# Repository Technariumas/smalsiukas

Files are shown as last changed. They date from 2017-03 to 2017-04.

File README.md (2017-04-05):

# smalsiukas
The conversion of a forklift trucks to a line following robot. 

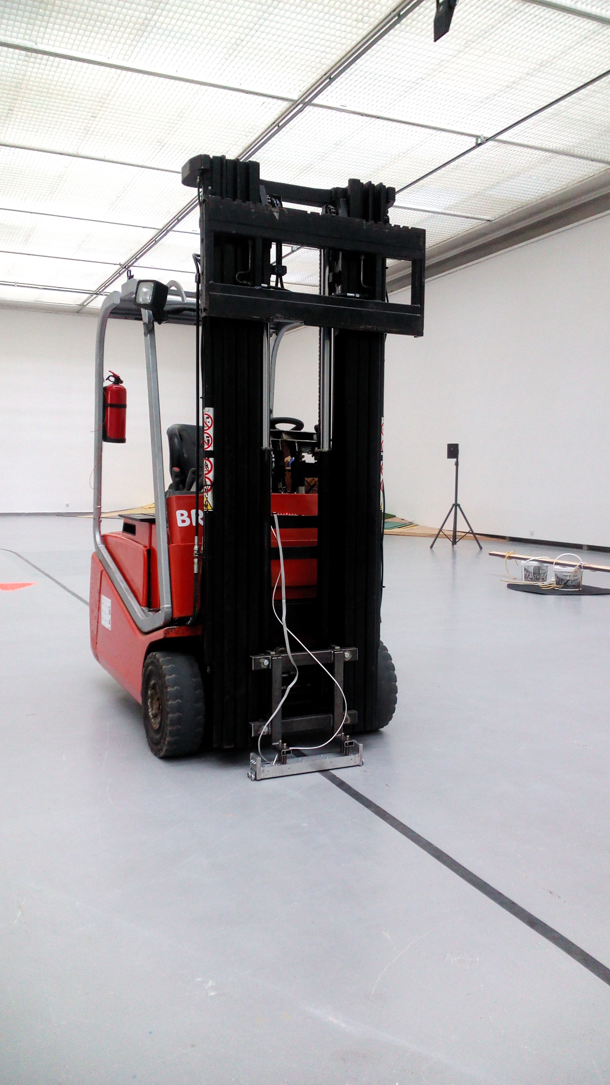
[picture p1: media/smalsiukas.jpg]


A file set related to conversion of BT C3E C4E forklift truck and Linde lifter to a line-following robot for an art installation of [Robertas Narkus "Träger"](http://cac.lt/en/exhibitions/future/8547)

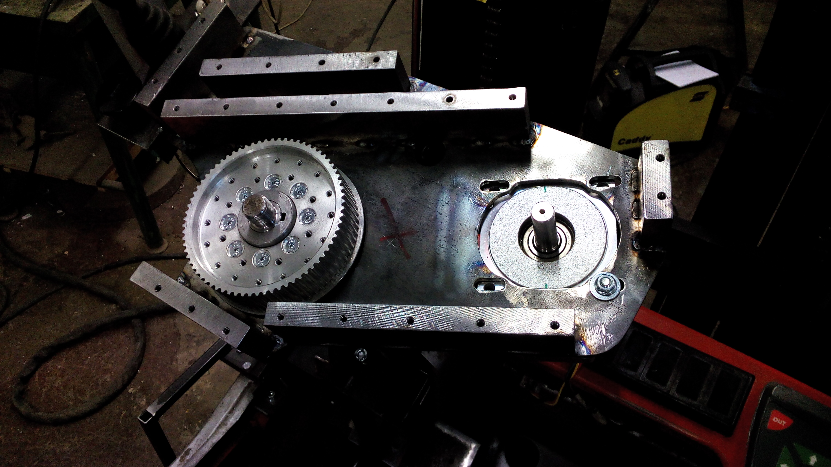
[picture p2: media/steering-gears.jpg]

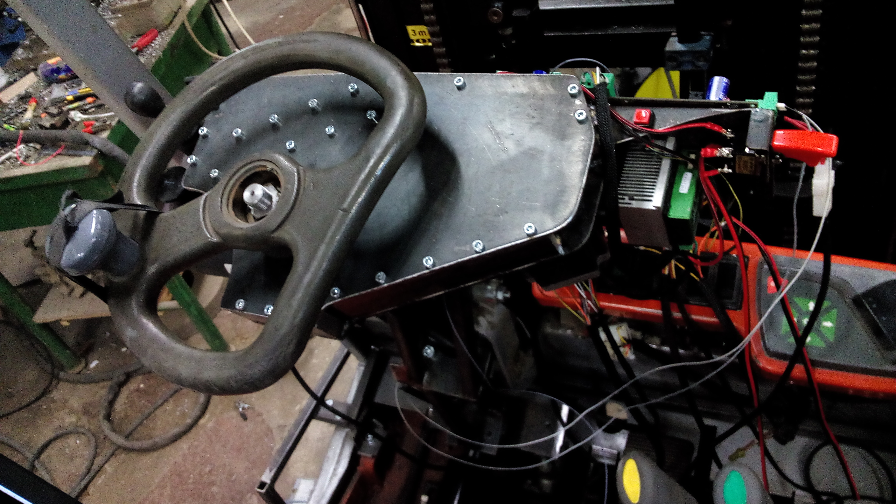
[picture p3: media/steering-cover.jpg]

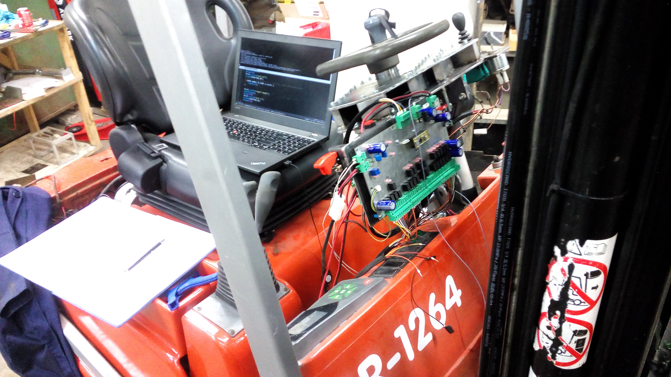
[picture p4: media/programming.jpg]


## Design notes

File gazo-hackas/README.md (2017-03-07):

#Gazo pedalo hackas

schema

##Faktai apie gazo pedalą
 
 * Egzistuoja SPDT jungiklis, kuris laiko užtrumpintus Juodą/Raudoną laidus, kol pedalas nenuspaustas ir Juodą/Mėlyną, kai nuspaustas. Perėjimas iš vienos būsenos į kitą turi būti "greitas", kitaip metama klaida **C4** - pedalo mygtuko klaida.
 * Egzistuoja potenciometras, sukiojamas pedalu jį spaudžiant. Potenciometro bendra varža - 3,6k, wiperio varža nuo potenciometro galų keičiasi 4,6k - 3,7k nuo "aukštojo" galo ir 1,2k - 2,12k nuo "žemojo" galo. Išvada - tai 3,6k potenciometras su 1k rezistoriumi ant išėjimo.
 * Į potenciometrą Žaliu laidu paduodama 10V įtampa, greičiausiai nuosekliai yra pajungtas 500 Omų rezistorius, nes pajungus potenciometrą ant Žalio laido įtampa pasikeičia į 8,7V
 * Keltuvas tikisi, kad potenciometras bus pajungtas ir ant Geltono laido bus ~8,7V, kitaip metama klaida **C6**
 * Kai pedalas nepaspaustas, keltuvas tikisi, kad ant Raudono laido (potenciometro wiperio) bus apie 0,22V, min 0,08V, jei Raudonas laidas paliekamas plaukiot arba pajungiamas prie potenciometro GND, metama klaida **C6**
 * Kai pedalas pilnai paspaustas, ant wiperio būna 2,36V
 * "Iš jausmo", atrodo, kad mums pilnai užtektų greičio ant wiperio esant 0,5V

##Hacko strategija:

  * Užtrumpinti mygtuko Juodą ir Raudoną laidus
  * Mygtuko laidų konfigūraciją perjunginėti rele, kad būtų "greitai"
  * Tarp Žalio ir Geltono laido pastatyti 3,6k rezistorių
  * Ant potenciometro Raudono laido paduoti valdančią įtampą referencintą nuo Geltono laido

##Galvaniškai atsietas Hackas

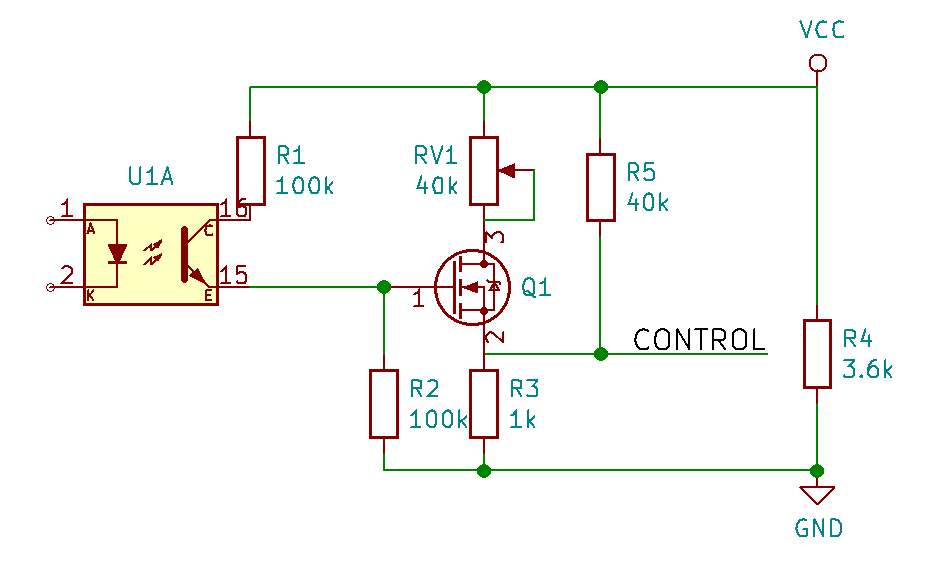
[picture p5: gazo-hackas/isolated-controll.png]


R4 apsimeta, kad pedalo potenciometras yra pajungtas, R5 ir R3 sukuria valdymo įtampą, imituojančią "nepaspaustą" pedalą. Per optoporą įjungus tranzistorių Q1, potenciometras RV1 pajungiamas lygiagrečiai su R5 tokiu būdu pakeliant valdymo įtampą. R2 pririša Q1 užtūrą, kad jis atsitiktinai nesijunginėtų. R1 ir R2 sudaro daliklį, kuris apsaugo Q1 užtūrą nuo viršįtampio.

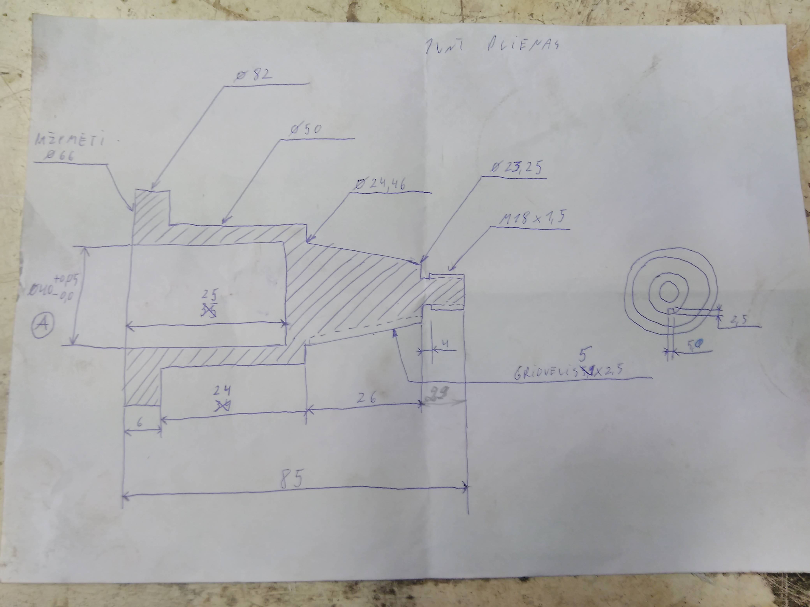
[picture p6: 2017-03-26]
Toyota/Mechanics/Blueprints/Toyota steering wheel hub blueprint.jpg

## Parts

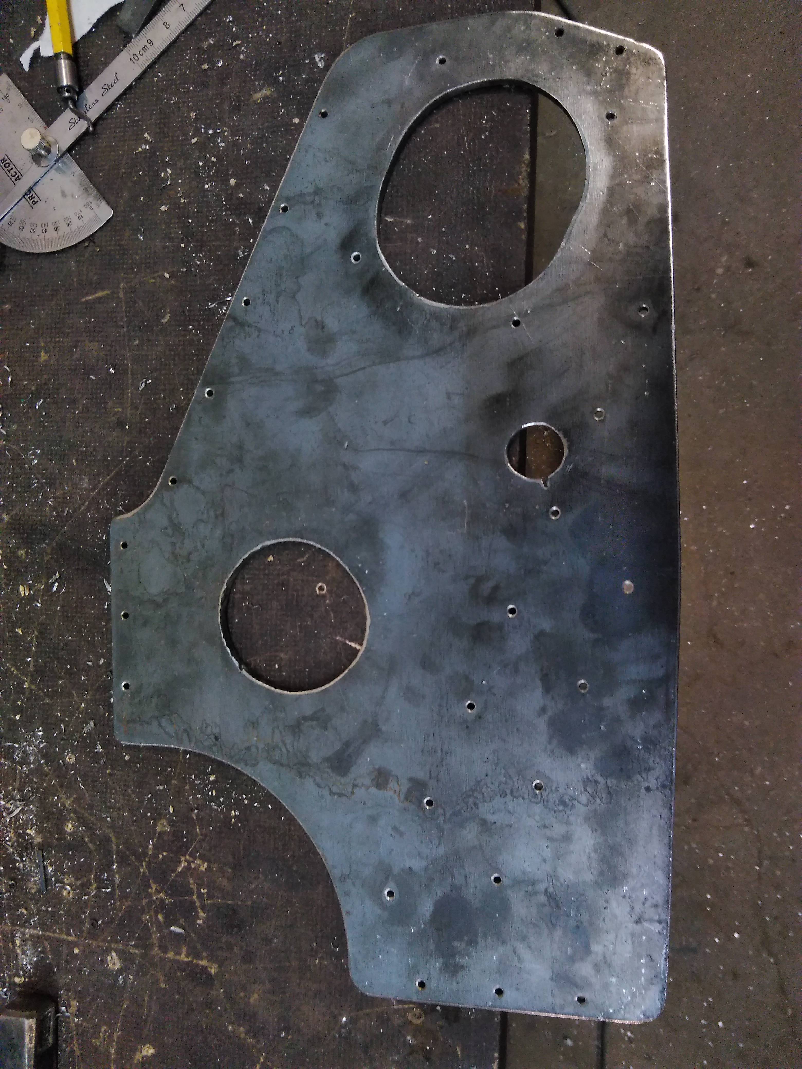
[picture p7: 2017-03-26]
Toyota/Mechanics/Parts/steering wheel/Toyota steering wheel plate.jpg

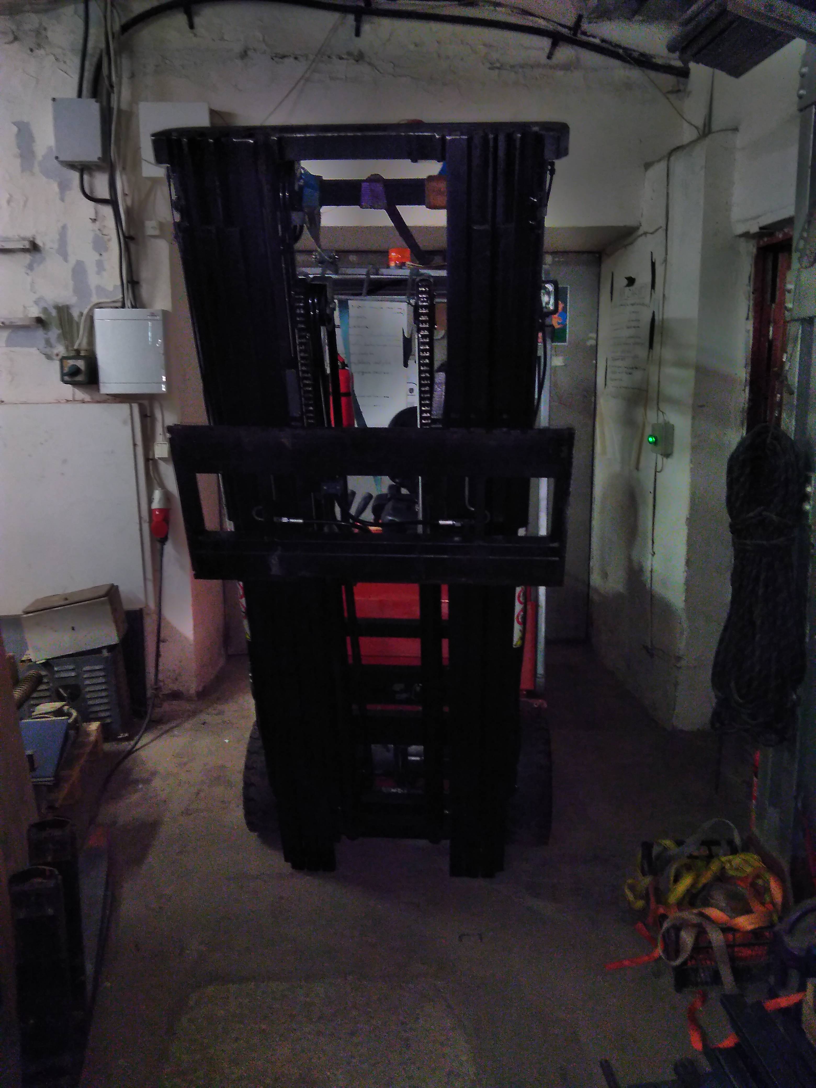
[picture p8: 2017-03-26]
Toyota/Mechanics/Parts/random/Getting in1.jpg

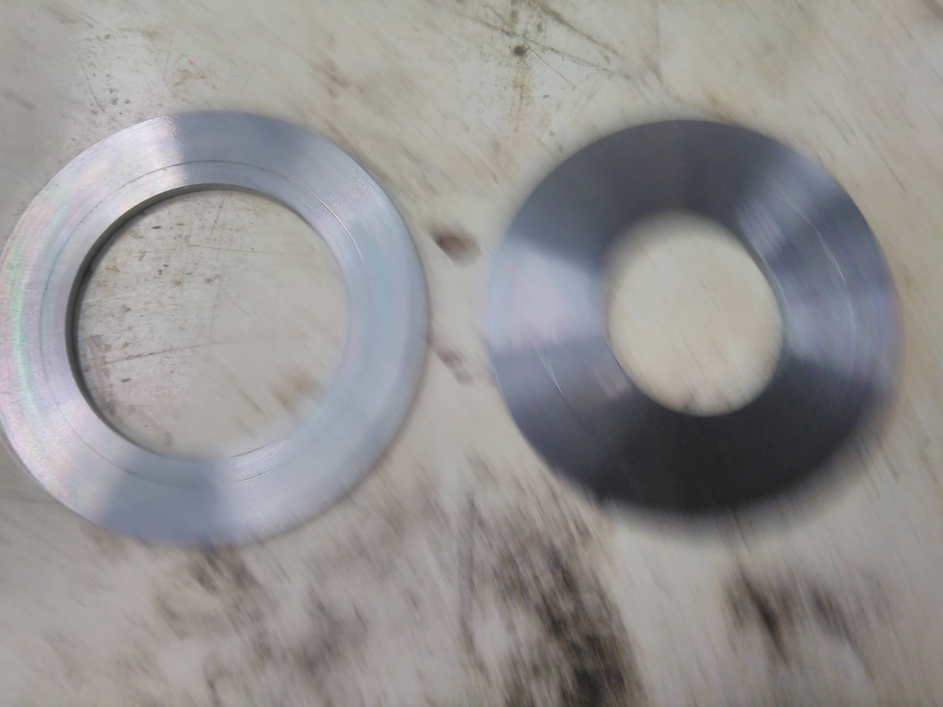
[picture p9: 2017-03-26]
Toyota/Mechanics/Parts/steering wheel/Toyota steering wheel parts.jpg

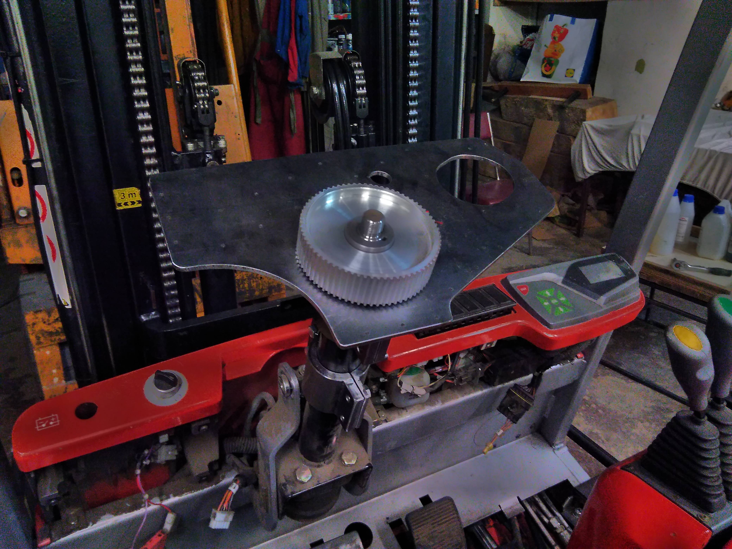
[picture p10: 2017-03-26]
Toyota/Mechanics/Parts/steering wheel/Toyota steering wheel attachment.jpg

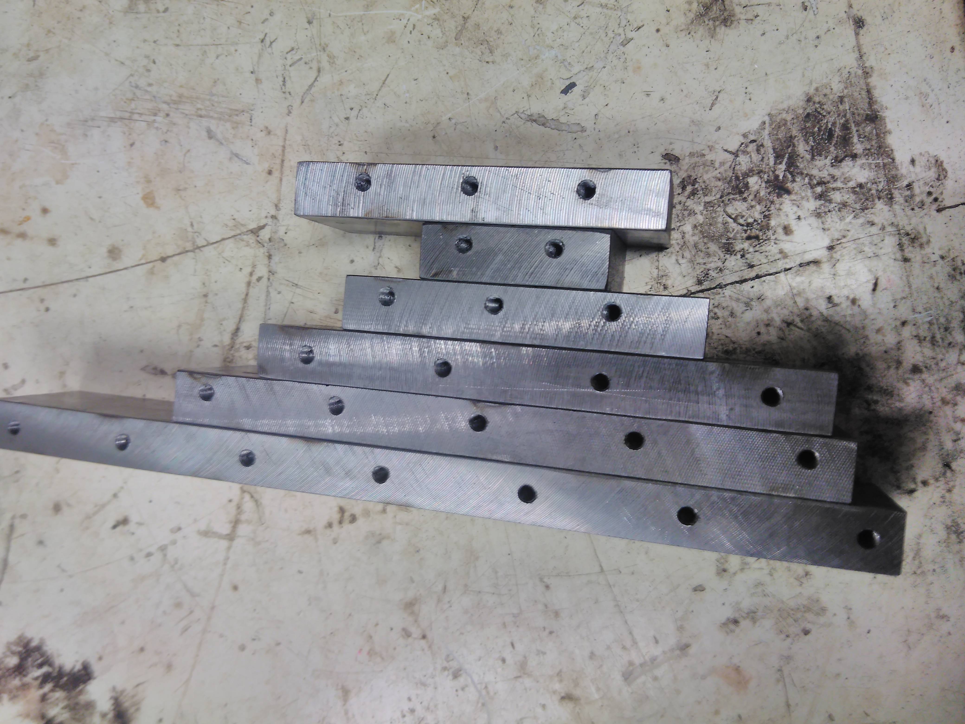
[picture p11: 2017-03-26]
Toyota/Mechanics/Parts/steering wheel/Toyota steering wheel plate standofs.jpg

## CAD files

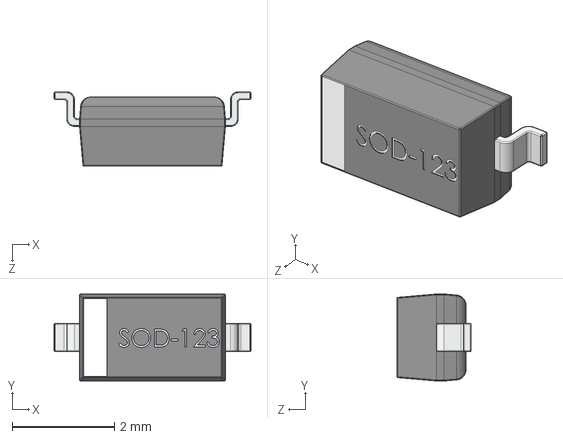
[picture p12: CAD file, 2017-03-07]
line-interface/User Library-SOD-123_DiodesInc.step
3.85 x 1.70 x 1.45 mm

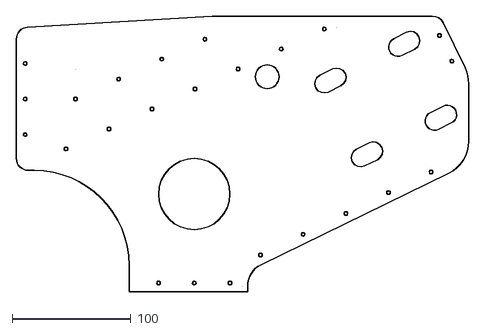
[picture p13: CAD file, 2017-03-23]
Toyota/Mechanics/Blueprints/Toyota drive wheel 1pcs 6mm stepper holes.dxf
381.2 x 232.5

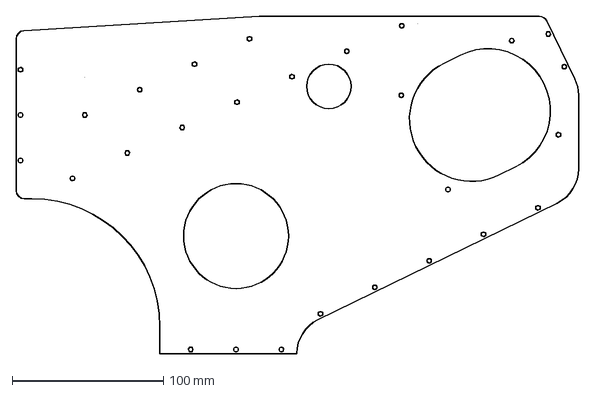
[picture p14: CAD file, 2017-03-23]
Toyota/Mechanics/Blueprints/Toyota drive wheel 2pcs 6mm ply scaled.dxf
371.8 x 223.1 mm

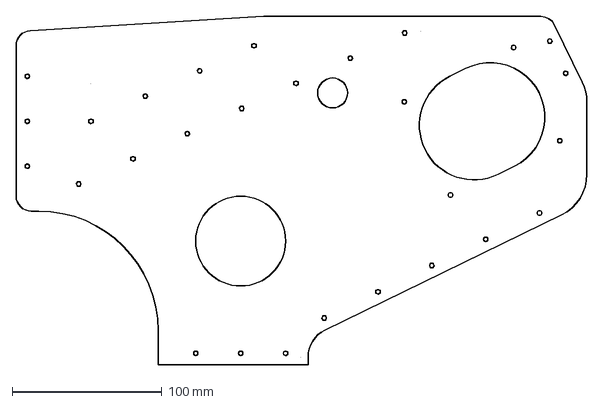
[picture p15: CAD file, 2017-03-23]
Toyota/Mechanics/Blueprints/Toyota drive wheel 1pcs 6mm ply normal.dxf
381.2 x 232.5 mm

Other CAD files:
Toyota/Mechanics/Blueprints/Toyota drive wheel plasma.dwg
Toyota/Mechanics/Blueprints/Toyota drive wheel 2pcs 6mm ply.dwg

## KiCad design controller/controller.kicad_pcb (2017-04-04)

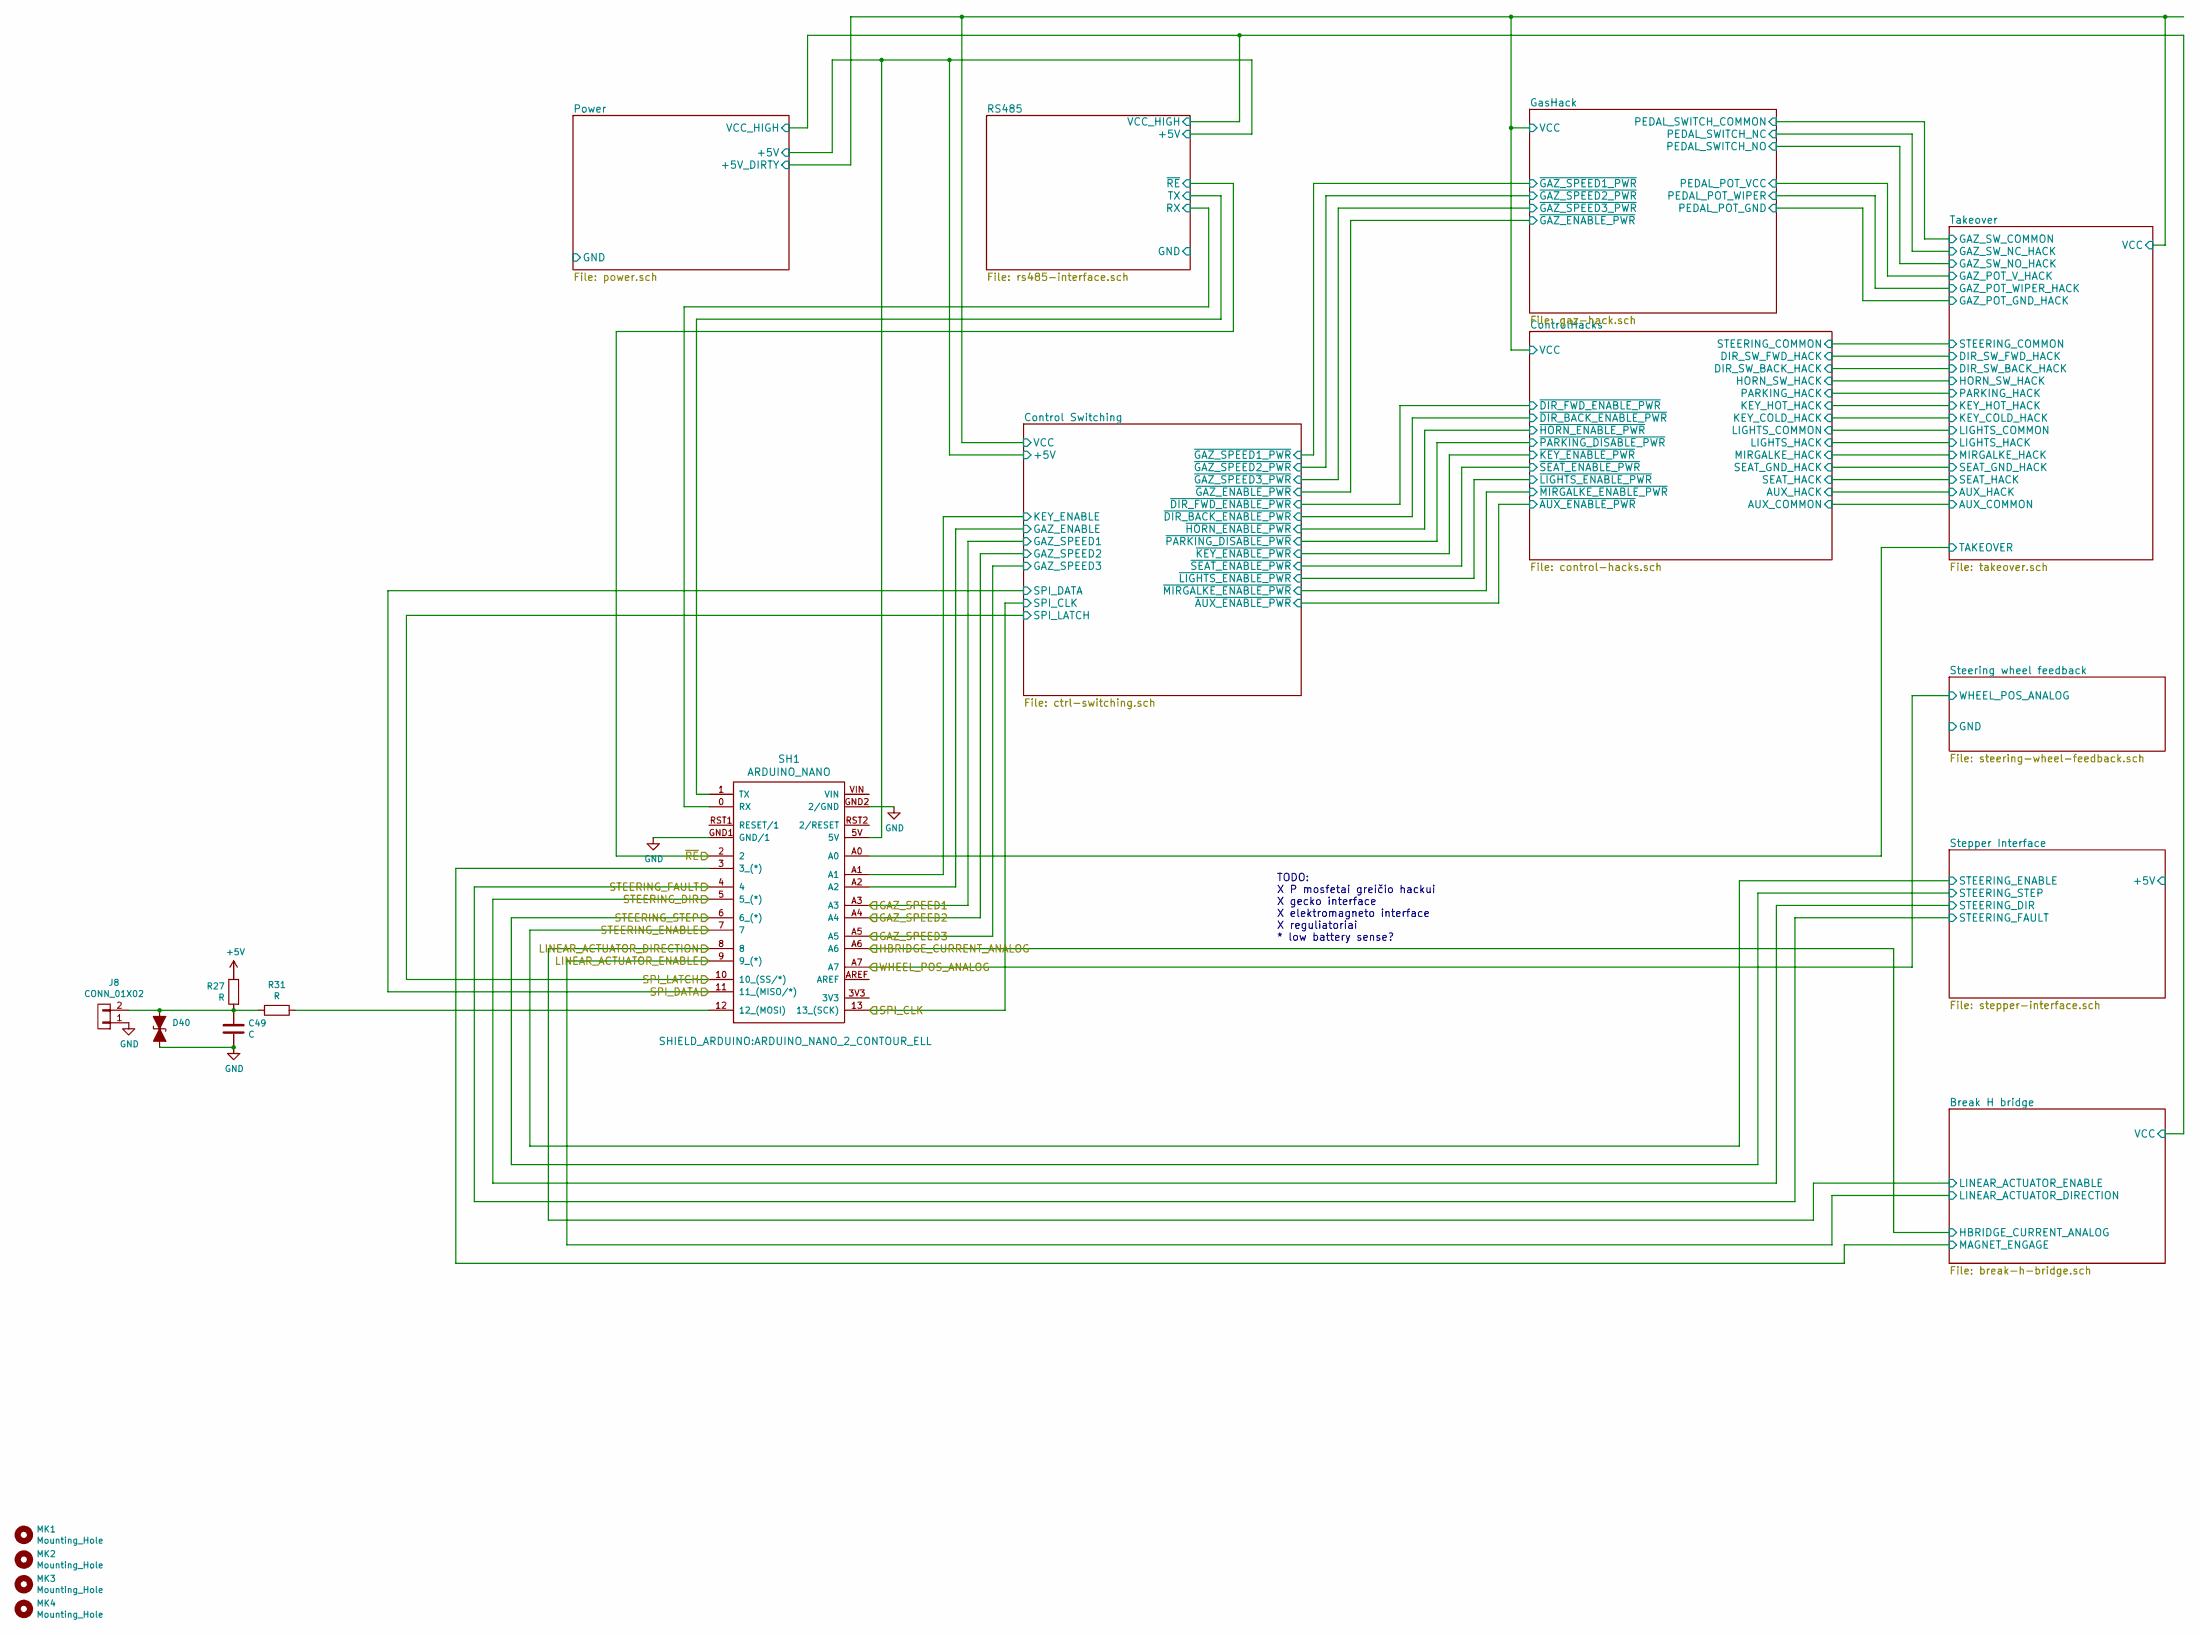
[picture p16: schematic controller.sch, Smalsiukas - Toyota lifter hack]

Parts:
C49: C; C_0603_HandSoldering; PartNo ?
D40: D_TVS_ALT; SOD-323; PartNo ?
J8: CONN_01X02; JST_EH_B02B-EH-A_02x2.50mm_Straight; PartNo ?
MK1, MK2, MK3, MK4: Mounting_Hole; MountingHole_3.2mm_M3; PartNo ?
R27, R31: R; R_0603_HandSoldering; PartNo ?
SH1: ARDUINO_NANO; ARDUINO_NANO_2_CONTOUR_ELL; PartNo ?

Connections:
+5V: R27.1, SH1.5V; also elsewhere on the board
/Break H bridge/MAGNET_ENGAGE: SH1.3 (3_(*)); also elsewhere on the board
/Control Switching/GAZ_ENABLE: SH1.A2; also elsewhere on the board
/Control Switching/KEY_ENABLE: SH1.A1; also elsewhere on the board
/GAZ_SPEED1: SH1.A3; also elsewhere on the board
/GAZ_SPEED2: SH1.A4; also elsewhere on the board
/GAZ_SPEED3: SH1.A5; also elsewhere on the board
/HBRIDGE_CURRENT_ANALOG: SH1.A6; also elsewhere on the board
/LINEAR_ACTUATOR_DIRECTION: SH1.8; also elsewhere on the board
/LINEAR_ACTUATOR_ENABLE: SH1.9 (9_(*)); also elsewhere on the board
/RS485/RX: SH1.0 (RX); also elsewhere on the board
/RS485/TX: SH1.1 (TX); also elsewhere on the board
/SPI_CLK: SH1.13 (13_(SCK)); also elsewhere on the board
/SPI_DATA: SH1.11 (11_(MISO/*)); also elsewhere on the board
/SPI_LATCH: SH1.10 (10_(SS/*)); also elsewhere on the board
/STEERING_DIR: SH1.5 (5_(*)); also elsewhere on the board
/STEERING_ENABLE: SH1.7; also elsewhere on the board
/STEERING_FAULT: SH1.4; also elsewhere on the board
/STEERING_STEP: SH1.6 (6_(*)); also elsewhere on the board
/Takeover/TAKEOVER: SH1.A0; also elsewhere on the board
/WHEEL_POS_ANALOG: SH1.A7; also elsewhere on the board
/~RE: SH1.2; also elsewhere on the board
GND: C49.2, D40.2 (A2), J8.1, SH1.GND1 (GND/1), SH1.GND2 (2/GND); also elsewhere on the board
unnamed: C49.1, D40.1 (A1), J8.2, R27.2, R31.2
unnamed: R31.1, SH1.12 (12_(MOSI))

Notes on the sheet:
TODO: X P mosfetai greičio hackui X gecko interface X elektromagneto interface X reguliatoriai * low battery sense?

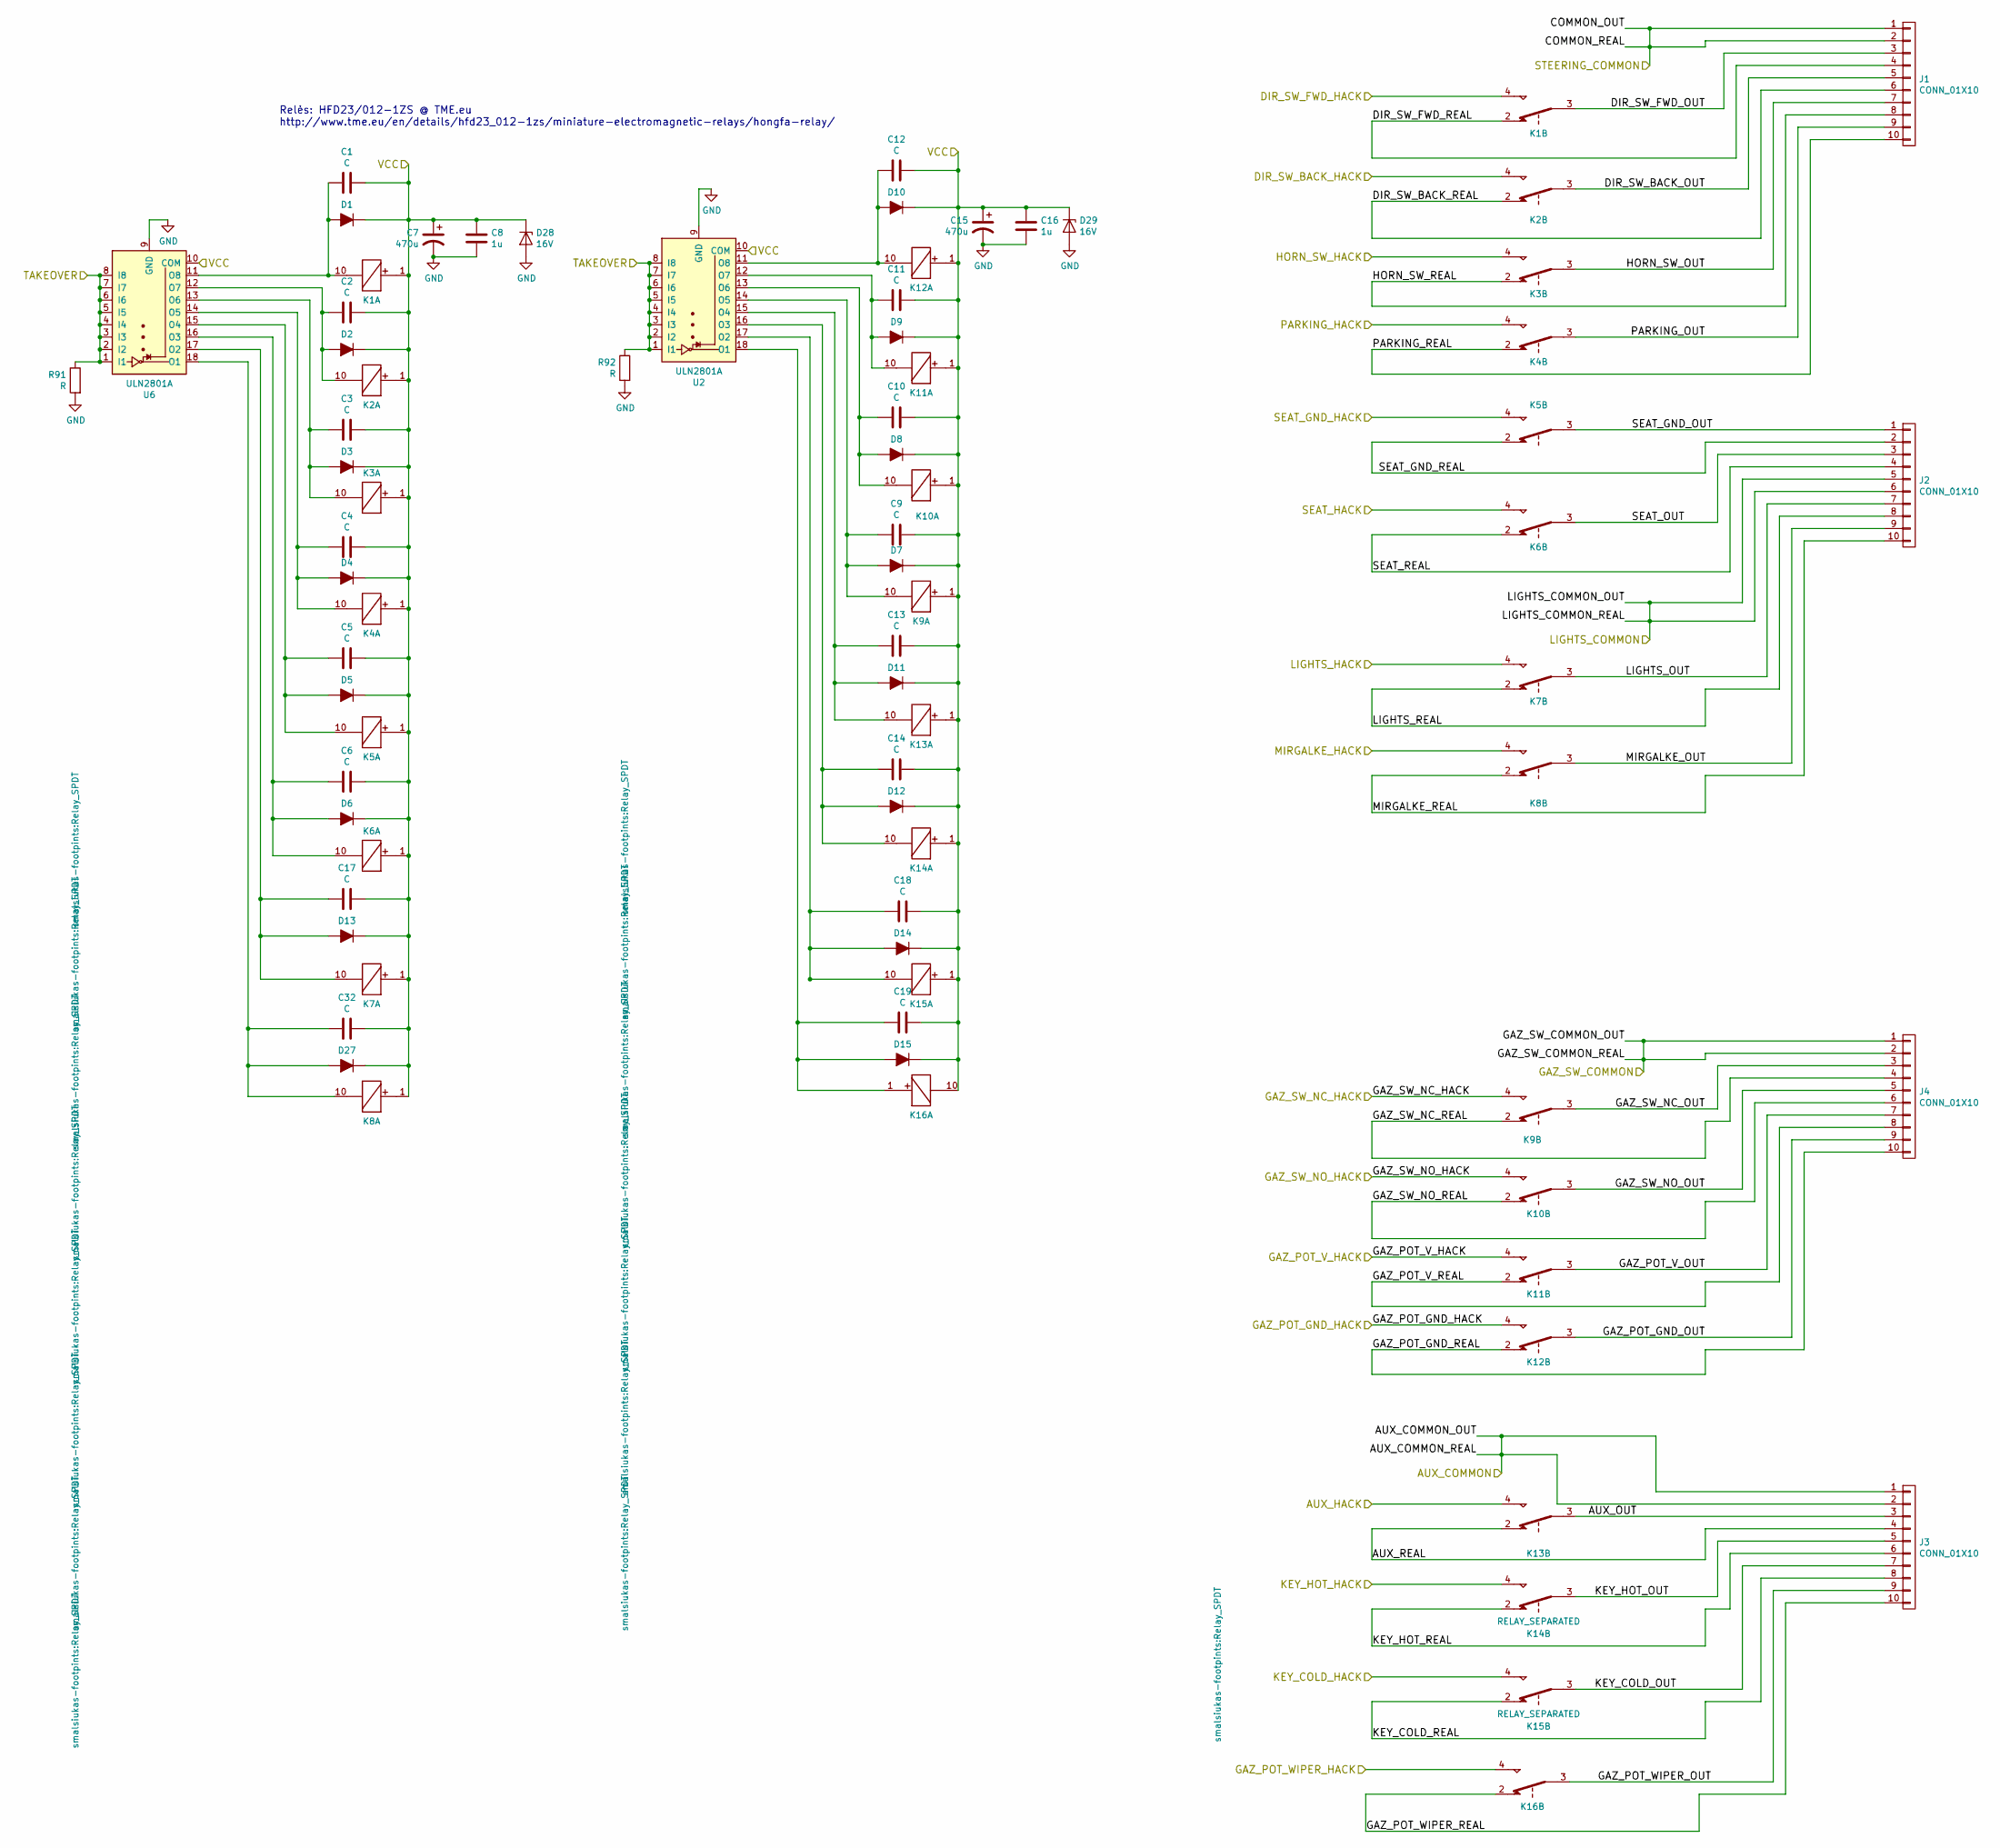
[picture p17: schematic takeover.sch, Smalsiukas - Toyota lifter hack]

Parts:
C1, C2, C3, C4, C5, C6, C9, C10, C11, C12, C13, C14, C17, C18, C19, C32: C; C_0603_HandSoldering; PartNo ?
C7, C15: 470u; CP_Radial_D16.0mm_P7.50mm; PartNo ECA2AAM471X
C8, C16: 1u; C_1210_HandSoldering; PartNo ?
D1: D_ALT; D_SOD-123; PartNo PMEG2020EH
D2, D3, D4, D5, D6, D7, D8, D9, D10, D11, D12, D13, D14, D15, D27: D_ALT; D_SOD-123; PartNo ?
D28, D29: 16V; D_SMB_Handsoldering; PartNo 1SMB5930BT3G
J1, J2, J3, J4: CONN_01X10; TerminalBlock_5.08-10pol; PartNo 21.95MH/10-E
K1, K2, K3, K4, K5, K6, K7, K8, K9, K10, K11, K12, K13, K14, K15, K16: RELAY_SEPARATED; Relay_SPDT; PartNo ?
R91, R92: R; R_0603_HandSoldering
U2, U6: ULN2801A; SOIC-18W_7.5x11.6mm_Pitch1.27mm; PartNo ULN2803ADWR

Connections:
/ControlHacks/AUX_COMMON: J3.1, J3.2; also elsewhere on the board
/ControlHacks/AUX_HACK: K13.4; also elsewhere on the board
/ControlHacks/DIR_SW_BACK_HACK: K2.4; also elsewhere on the board
/ControlHacks/DIR_SW_FWD_HACK: K1.4; also elsewhere on the board
/ControlHacks/HORN_SW_HACK: K3.4; also elsewhere on the board
/ControlHacks/KEY_COLD_HACK: K15.4; also elsewhere on the board
/ControlHacks/KEY_HOT_HACK: K14.4; also elsewhere on the board
/ControlHacks/LIGHTS_COMMON: J2.5, J2.6; also elsewhere on the board
/ControlHacks/LIGHTS_HACK: K7.4; also elsewhere on the board
/ControlHacks/MIRGALKE_HACK: K8.4; also elsewhere on the board
/ControlHacks/PARKING_HACK: K4.4; also elsewhere on the board
/ControlHacks/SEAT_GND_HACK: K5.4; also elsewhere on the board
/ControlHacks/SEAT_HACK: K6.4; also elsewhere on the board
/ControlHacks/STEERING_COMMON: J1.1, J1.2; also elsewhere on the board
/Power/+5V_DIRTY: C1.1, C2.1, C3.1, C4.1, C5.1, C6.1, C7.1, C8.2, C9.1, C10.1, C11.1, C12.1, C13.1, C14.1, C15.1, C16.2, C17.1, C18.1, C19.1, C32.1, D1.1 (K), D2.1 (K), D3.1 (K), D4.1 (K), D5.1 (K), D6.1 (K), D7.1 (K), D8.1 (K), D9.1 (K), D10.1 (K), D11.1 (K), D12.1 (K), D13.1 (K), D14.1 (K), D15.1 (K), D27.1 (K), D28.1 (K), D29.1 (K), K1.1, K2.1, K3.1, K4.1, K5.1, K6.1, K7.1, K8.1, K9.1, K10.1, K11.1, K12.1, K13.1, K14.1, K15.1, K16.10, U2.10 (COM), U6.10 (COM); also elsewhere on the board
/Takeover/AUX_OUT: J3.3, K13.3
/Takeover/AUX_REAL: J3.4, K13.2
/Takeover/DIR_SW_BACK_OUT: J1.5, K2.3
/Takeover/DIR_SW_BACK_REAL: J1.6, K2.2
/Takeover/DIR_SW_FWD_OUT: J1.3, K1.3
/Takeover/DIR_SW_FWD_REAL: J1.4, K1.2
/Takeover/GAZ_POT_GND_HACK: K12.4; also elsewhere on the board
/Takeover/GAZ_POT_GND_OUT: J4.9, K12.3
/Takeover/GAZ_POT_GND_REAL: J4.10, K12.2
/Takeover/GAZ_POT_V_HACK: K11.4; also elsewhere on the board
/Takeover/GAZ_POT_V_OUT: J4.7, K11.3
/Takeover/GAZ_POT_V_REAL: J4.8, K11.2
/Takeover/GAZ_POT_WIPER_HACK: K16.4; also elsewhere on the board
/Takeover/GAZ_POT_WIPER_OUT: J3.9, K16.3
/Takeover/GAZ_POT_WIPER_REAL: J3.10, K16.2
/Takeover/GAZ_SW_COMMON: J4.1, J4.2; also elsewhere on the board
/Takeover/GAZ_SW_NC_HACK: K9.4; also elsewhere on the board
/Takeover/GAZ_SW_NC_OUT: J4.3, K9.3
/Takeover/GAZ_SW_NC_REAL: J4.4, K9.2
/Takeover/GAZ_SW_NO_HACK: K10.4; also elsewhere on the board
/Takeover/GAZ_SW_NO_OUT: J4.5, K10.3
/Takeover/GAZ_SW_NO_REAL: J4.6, K10.2
/Takeover/HORN_SW_OUT: J1.7, K3.3
/Takeover/HORN_SW_REAL: J1.8, K3.2
/Takeover/KEY_COLD_OUT: J3.7, K15.3
/Takeover/KEY_COLD_REAL: J3.8, K15.2
/Takeover/KEY_HOT_OUT: J3.5, K14.3
/Takeover/KEY_HOT_REAL: J3.6, K14.2
/Takeover/LIGHTS_OUT: J2.7, K7.3
/Takeover/LIGHTS_REAL: J2.8, K7.2
/Takeover/MIRGALKE_OUT: J2.9, K8.3
/Takeover/MIRGALKE_REAL: J2.10, K8.2
/Takeover/PARKING_OUT: J1.9, K4.3
/Takeover/PARKING_REAL: J1.10, K4.2
/Takeover/SEAT_GND_OUT: J2.1, K5.3
/Takeover/SEAT_GND_REAL: J2.2, K5.2
/Takeover/SEAT_OUT: J2.3, K6.3
/Takeover/SEAT_REAL: J2.4, K6.2
/Takeover/TAKEOVER: R91.1, R92.1, U2.1 (I1), U2.2 (I2), U2.3 (I3), U2.4 (I4), U2.5 (I5), U2.6 (I6), U2.7 (I7), U2.8 (I8), U6.1 (I1), U6.2 (I2), U6.3 (I3), U6.4 (I4), U6.5 (I5), U6.6 (I6), U6.7 (I7), U6.8 (I8); also elsewhere on the board
GND: C7.2, C8.1, C15.2, C16.1, D28.2 (A), D29.2 (A), R91.2, R92.2, U2.9 (GND), U6.9 (GND); also elsewhere on the board
unnamed: C1.2, D1.2 (A), K1.10, U6.11 (O8)
unnamed: C2.2, D2.2 (A), K2.10, U6.12 (O7)
unnamed: C3.2, D3.2 (A), K3.10, U6.13 (O6)
unnamed: C4.2, D4.2 (A), K4.10, U6.14 (O5)
unnamed: C5.2, D5.2 (A), K5.10, U6.15 (O4)
unnamed: C6.2, D6.2 (A), K6.10, U6.16 (O3)
unnamed: C9.2, D7.2 (A), K9.10, U2.14 (O5)
unnamed: C10.2, D8.2 (A), K10.10, U2.13 (O6)
unnamed: C11.2, D9.2 (A), K11.10, U2.12 (O7)
unnamed: C12.2, D10.2 (A), K12.10, U2.11 (O8)
unnamed: C13.2, D11.2 (A), K13.10, U2.15 (O4)
unnamed: C14.2, D12.2 (A), K14.10, U2.16 (O3)
unnamed: C17.2, D13.2 (A), K7.10, U6.17 (O2)
unnamed: C18.2, D14.2 (A), K15.10, U2.17 (O2)
unnamed: C19.2, D15.2 (A), K16.1, U2.18 (O1)
unnamed: C32.2, D27.2 (A), K8.10, U6.18 (O1)

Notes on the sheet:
Relės: HFD23/012-1ZS @ TME.eu http://www.tme.eu/en/details/hfd23_012-1zs/miniature-electromagnetic-relays/hongfa-relay/

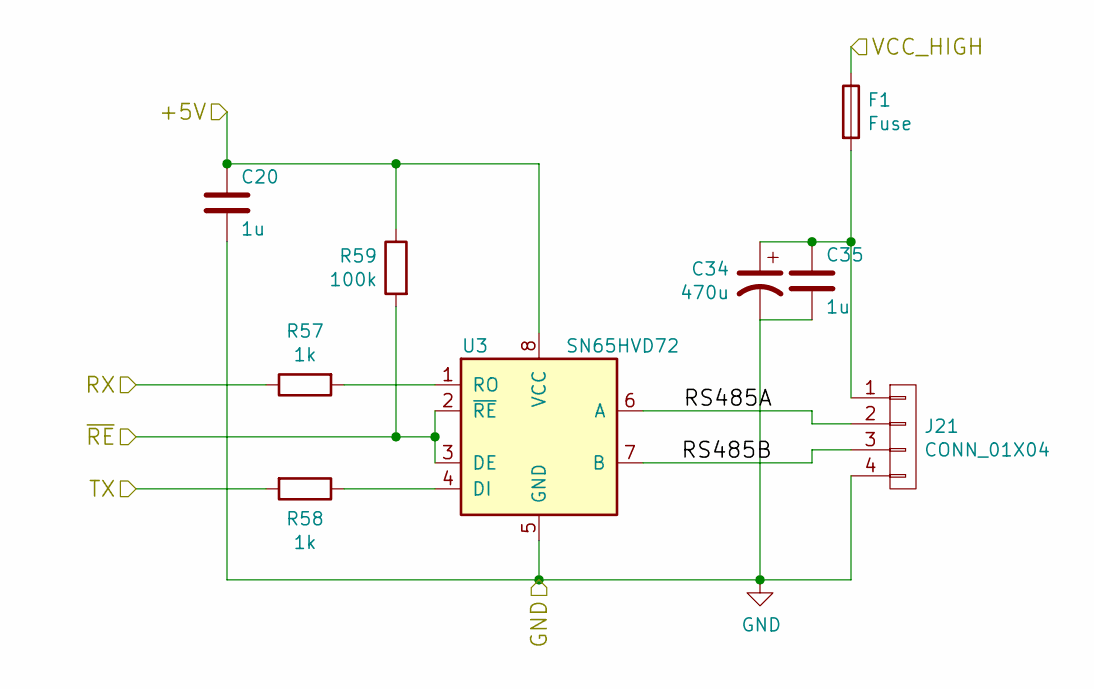
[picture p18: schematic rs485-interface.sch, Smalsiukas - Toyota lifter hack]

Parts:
C20, C35: 1u; C_0603_HandSoldering
C34: 470u; CP_Radial_D16.0mm_P7.50mm; PartNo ECA2AAM471X
F1: Fuse; Automotive-Fuse-Holder; PartNo ?
J21: CONN_01X04; JST_EH_B04B-EH-A_04x2.50mm_Straight; PartNo ?
R57, R58: 1k; R_0603_HandSoldering
R59: 100k; R_0603_HandSoldering
U3: SN65HVD72; SOIC-8_3.9x4.9mm_Pitch1.27mm; PartNo MAX13442EASA

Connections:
+5V: C20.1, R59.1, U3.8 (VCC); also elsewhere on the board
/RS485/RS485A: J21.2, U3.6 (A)
/RS485/RS485B: J21.3, U3.7 (B)
/RS485/RX: R57.1; also elsewhere on the board
/RS485/TX: R58.2; also elsewhere on the board
/~RE: R59.2, U3.2 (~RE~), U3.3 (DE); also elsewhere on the board
GND: C20.2, C34.2, C35.2, J21.4, U3.5 (GND); also elsewhere on the board
unnamed: C34.1, C35.1, F1.2, J21.1
unnamed: R57.2, U3.1 (RO)
unnamed: R58.1, U3.4 (DI)
VCC: F1.1; also elsewhere on the board

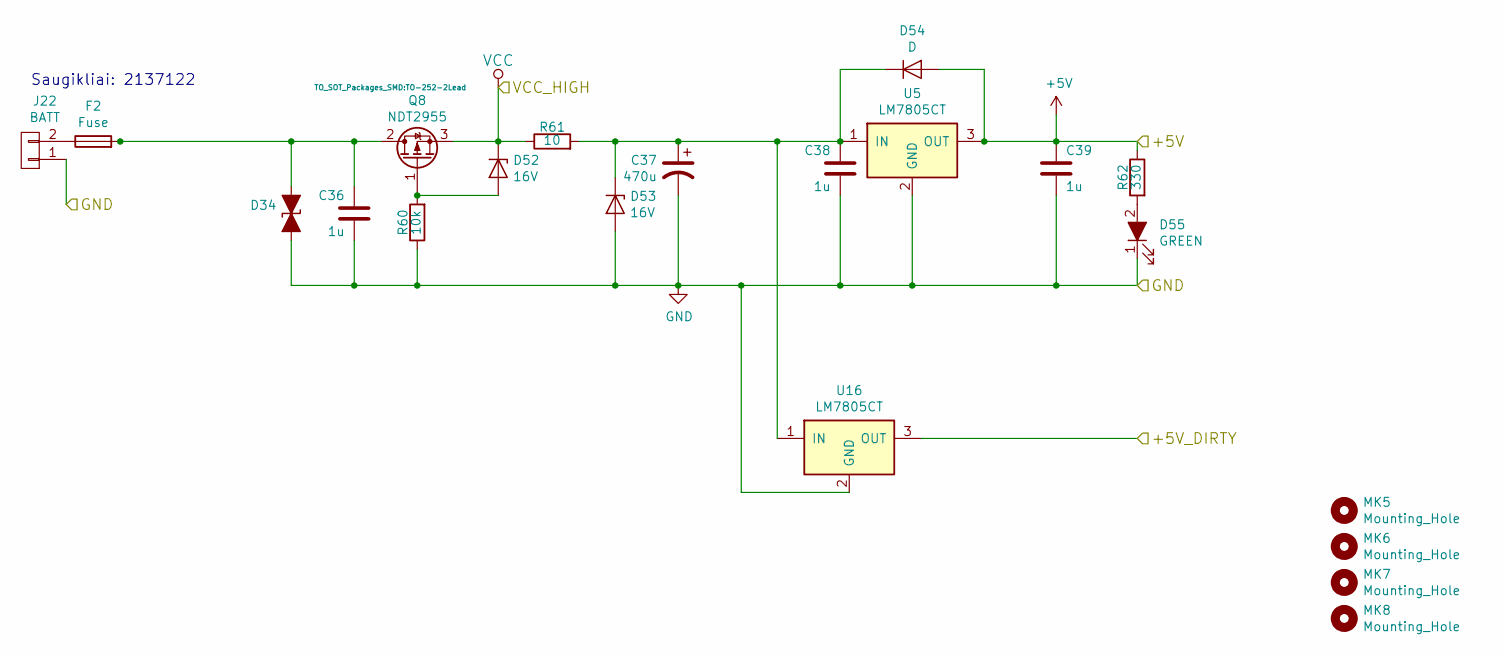
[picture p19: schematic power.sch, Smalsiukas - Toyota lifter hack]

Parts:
C36, C38: 1u; C_1210_HandSoldering; PartNo ?
C37: 470u; CP_Radial_D16.0mm_P7.50mm; PartNo ECA2AAM471X
C39: 1u; C_0603
D34: D_TVS_ALT; Diode-SMC_Handsoldering; PartNo ?
D52, D53: 16V; D_SMB_Handsoldering; PartNo 1SMB5930BT3G
D54: D; D_SOD-123; PartNo ?
D55: GREEN; LED_D5.0mm; PartNo ?
F2: Fuse; Automotive-Fuse-Holder; PartNo ?
J22: BATT; TerminalBlock_5.08-2pol; PartNo ?
MK5, MK6, MK7, MK8: Mounting_Hole; MountingHole_3.2mm_M3; PartNo ?
Q8: NDT2955; TO-252-2Lead; PartNo IRFR5410TRPBF
R60: 10k; R_0603_HandSoldering; PartNo ?
R61: 10; R_0805_HandSoldering; PartNo ?
R62: 330; R_0603
U5: LM7805CT; TO-252-2Lead; PartNo KA7805ERTF
U16: LM7805CT; TO-220_Vertical; PartNo OKI-78SR-5/1.5-W36-C

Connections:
+5V: C39.1, D54.2 (A), R62.1, U5.3 (OUT); also elsewhere on the board
/Power/+5V_DIRTY: U16.3 (OUT); also elsewhere on the board
GND: C36.2, C37.2, C38.2, C39.2, D34.2 (A2), D53.2 (A), D55.1 (K), J22.1, R60.1, U5.2 (GND), U16.2 (GND); also elsewhere on the board
unnamed: C36.1, D34.1 (A1), F2.2, Q8.2 (D)
unnamed: C37.1, C38.1, D53.1 (K), D54.1 (K), R61.2, U5.1 (IN), U16.1 (IN)
unnamed: D52.2 (A), Q8.1 (G), R60.2
unnamed: D55.2 (A), R62.2
unnamed: F2.1, J22.2
VCC: D52.1 (K), Q8.3 (S), R61.1; also elsewhere on the board

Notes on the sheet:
Saugikliai: 2137122

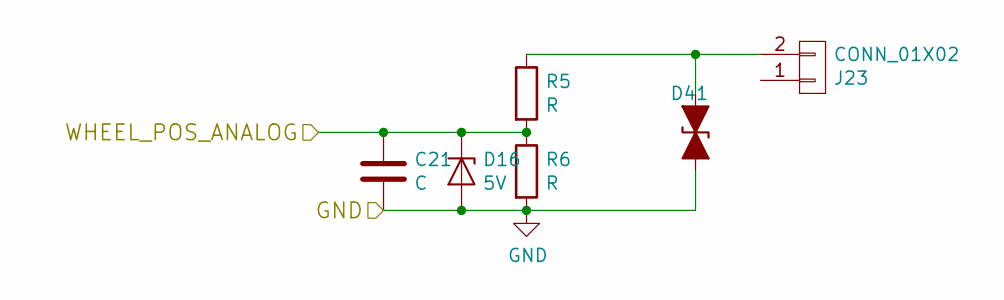
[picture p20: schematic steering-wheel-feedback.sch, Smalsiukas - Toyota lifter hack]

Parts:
C21: C; C_0603_HandSoldering
D16: 5V; SOD-123; PartNo ?
D41: D_TVS_ALT; SOD-323; PartNo ?
J23: CONN_01X02; TerminalBlock_5.08-2pol; PartNo ?
R5, R6: R; R_0603_HandSoldering

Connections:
/WHEEL_POS_ANALOG: C21.1, D16.1 (K), R5.2, R6.1; also elsewhere on the board
GND: C21.2, D16.2 (A), D41.2 (A2), R6.2; also elsewhere on the board
unnamed: D41.1 (A1), J23.2, R5.1

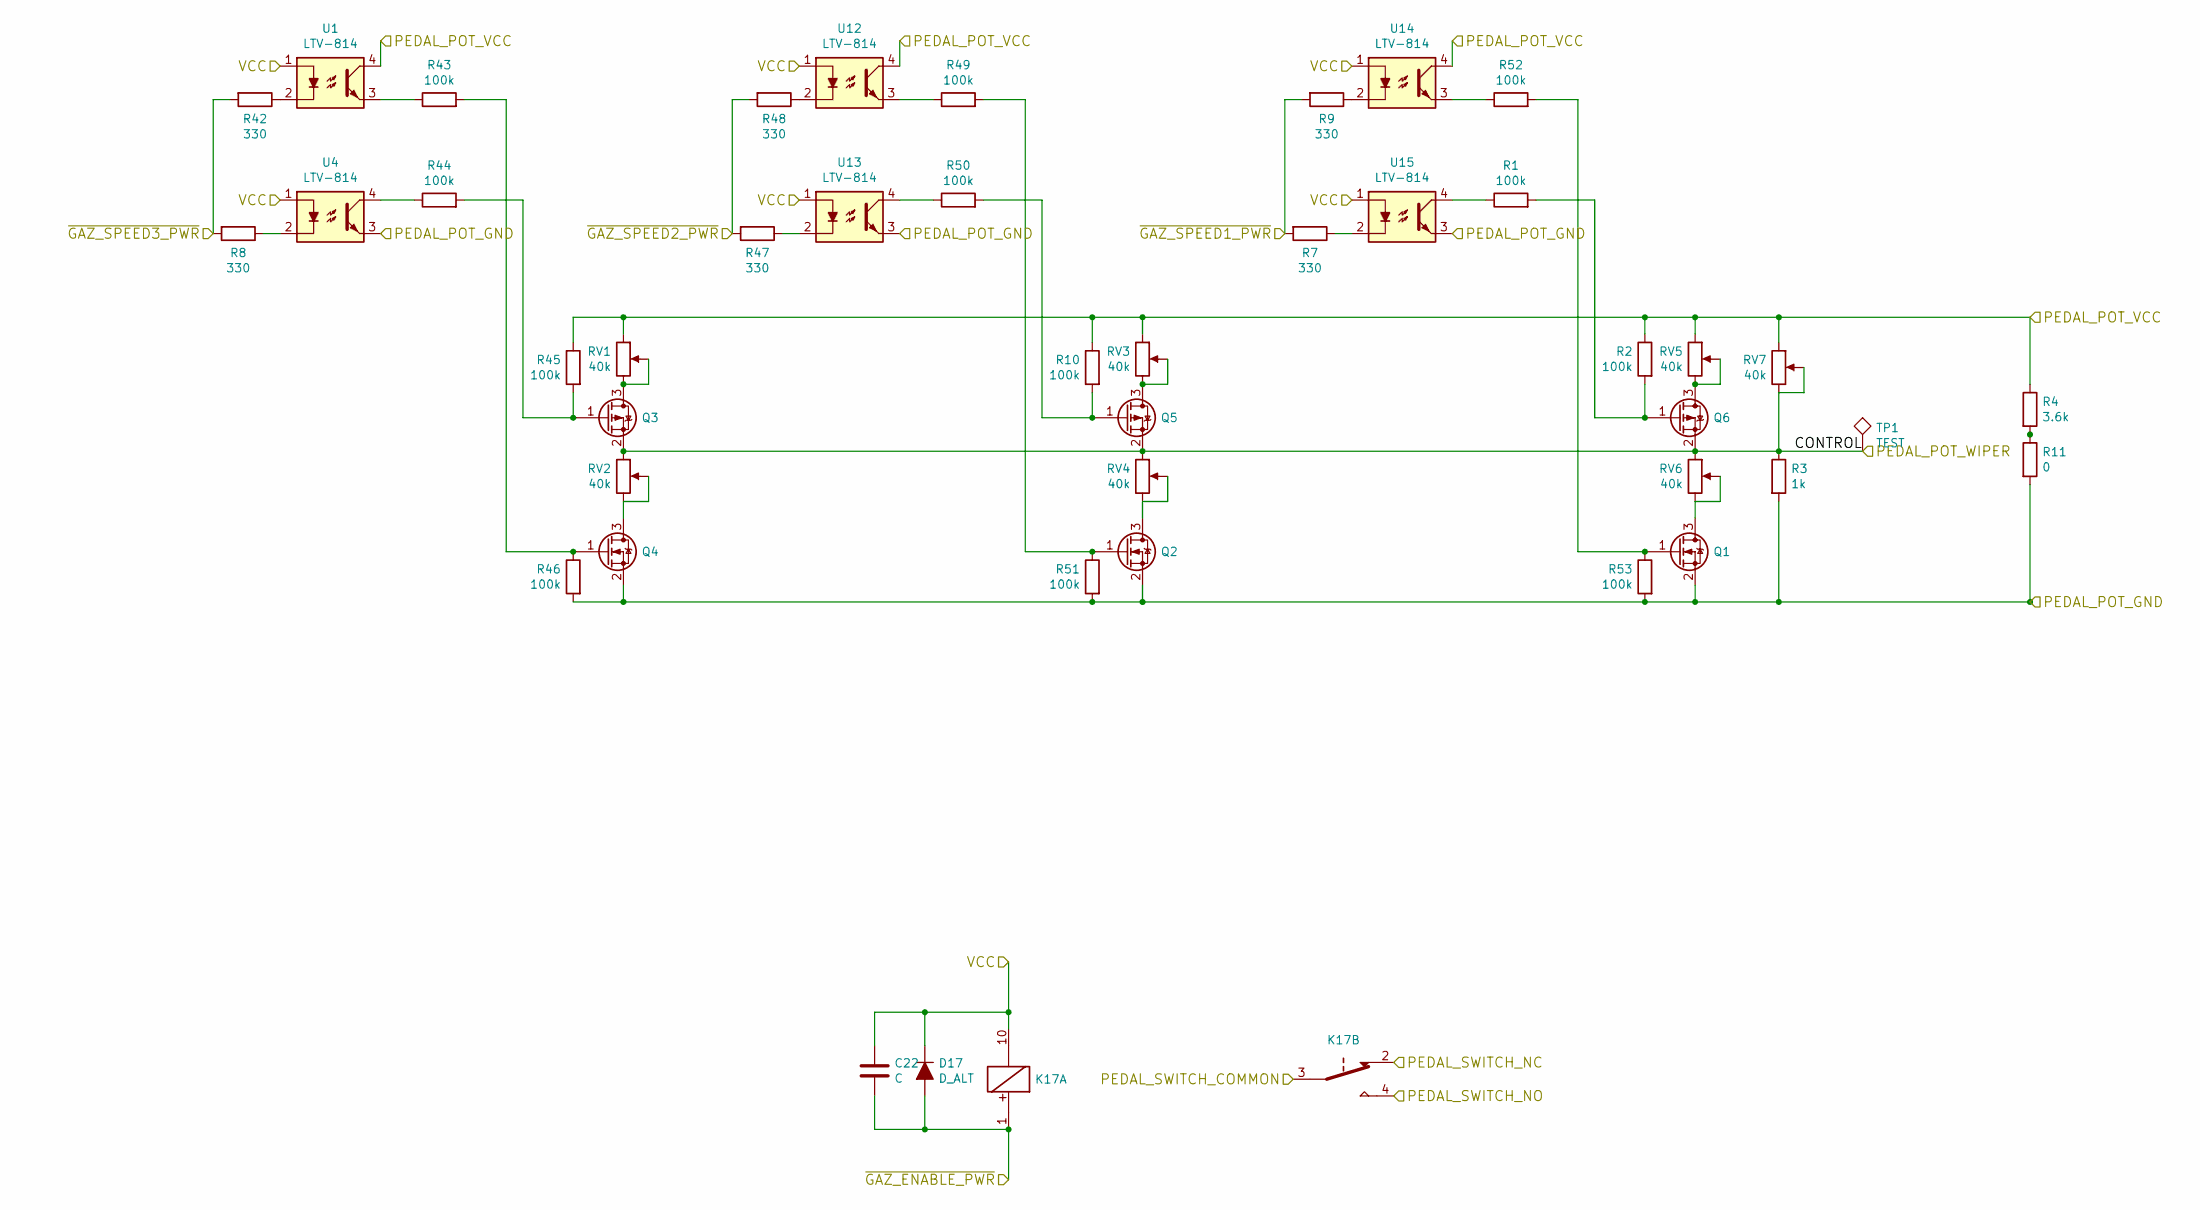
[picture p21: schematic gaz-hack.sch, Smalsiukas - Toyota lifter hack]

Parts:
C22: C; C_0603_HandSoldering
D17: D_ALT; D_SOD-123
K17: RELAY_SEPARATED; Relay_SPDT
Q1, Q2, Q4: Q_NMOS_GSD; SOT-23_Handsoldering; PartNo ?
Q3, Q5, Q6: Q_PMOS_GSD; SOT-23_Handsoldering; PartNo ?
R1, R2, R10, R43, R44, R45, R46, R49, R50, R51, R52, R53: 100k; R_0603_HandSoldering
R3: 1k; R_0603_HandSoldering
R4: 3.6k; R_0603_HandSoldering
R7, R8, R9, R42, R47, R48: 330; R_0603_HandSoldering
R11: 0; R_0603_HandSoldering
RV1, RV2, RV3, RV4, RV5, RV6, RV7: 40k; Potentiometer_Trimmer_Bourns_3296W; PartNo ?
TP1: TEST; Measurement_Point_Round-TH_Small; PartNo ?
U1, U4, U12, U13, U14, U15: LTV-814; DIP-4_W11.48mm_SMD; PartNo ?

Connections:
/Control Switching/~GAZ_ENABLE_PWR: C22.2, D17.2 (A), K17.1; also elsewhere on the board
/Control Switching/~GAZ_SPEED1_PWR: R7.2, R9.2; also elsewhere on the board
/Control Switching/~GAZ_SPEED2_PWR: R47.2, R48.2; also elsewhere on the board
/Control Switching/~GAZ_SPEED3_PWR: R8.2, R42.2; also elsewhere on the board
/Power/+5V_DIRTY: C22.1, D17.1 (K), K17.10, U1.1, U4.1, U12.1, U13.1, U14.1, U15.1; also elsewhere on the board
/Takeover/GAZ_POT_GND_HACK: Q1.2 (S), Q2.2 (S), Q4.2 (S), R3.2, R11.2, R46.2, R51.2, R53.2, U4.3, U13.3, U15.3; also elsewhere on the board
/Takeover/GAZ_POT_V_HACK: R2.1, R4.1, R10.1, R45.1, RV1.1, RV3.1, RV5.1, RV7.1, U1.4, U12.4, U14.4; also elsewhere on the board
/Takeover/GAZ_POT_WIPER_HACK: Q3.2 (S), Q5.2 (S), Q6.2 (S), R3.1, RV2.1, RV4.1, RV6.1, RV7.2, RV7.3, TP1.1; also elsewhere on the board
/Takeover/GAZ_SW_COMMON: K17.3; also elsewhere on the board
/Takeover/GAZ_SW_NC_HACK: K17.2; also elsewhere on the board
/Takeover/GAZ_SW_NO_HACK: K17.4; also elsewhere on the board
unnamed: Q1.1 (G), R52.2, R53.1
unnamed: Q1.3 (D), RV6.2, RV6.3
unnamed: Q2.1 (G), R49.2, R51.1
unnamed: Q2.3 (D), RV4.2, RV4.3
unnamed: Q3.1 (G), R44.2, R45.2
unnamed: Q3.3 (D), RV1.2, RV1.3
unnamed: Q4.1 (G), R43.2, R46.1
unnamed: Q4.3 (D), RV2.2, RV2.3
unnamed: Q5.1 (G), R10.2, R50.2
unnamed: Q5.3 (D), RV3.2, RV3.3
unnamed: Q6.1 (G), R1.2, R2.2
unnamed: Q6.3 (D), RV5.2, RV5.3
unnamed: R1.1, U15.4
unnamed: R7.1, U15.2
unnamed: R8.1, U4.2
unnamed: R9.1, U14.2
unnamed: R4.2, R11.1
unnamed: R42.1, U1.2
unnamed: R43.1, U1.3
unnamed: R44.1, U4.4
unnamed: R47.1, U13.2
unnamed: R48.1, U12.2
unnamed: R49.1, U12.3
unnamed: R50.1, U13.4
unnamed: R52.1, U14.3

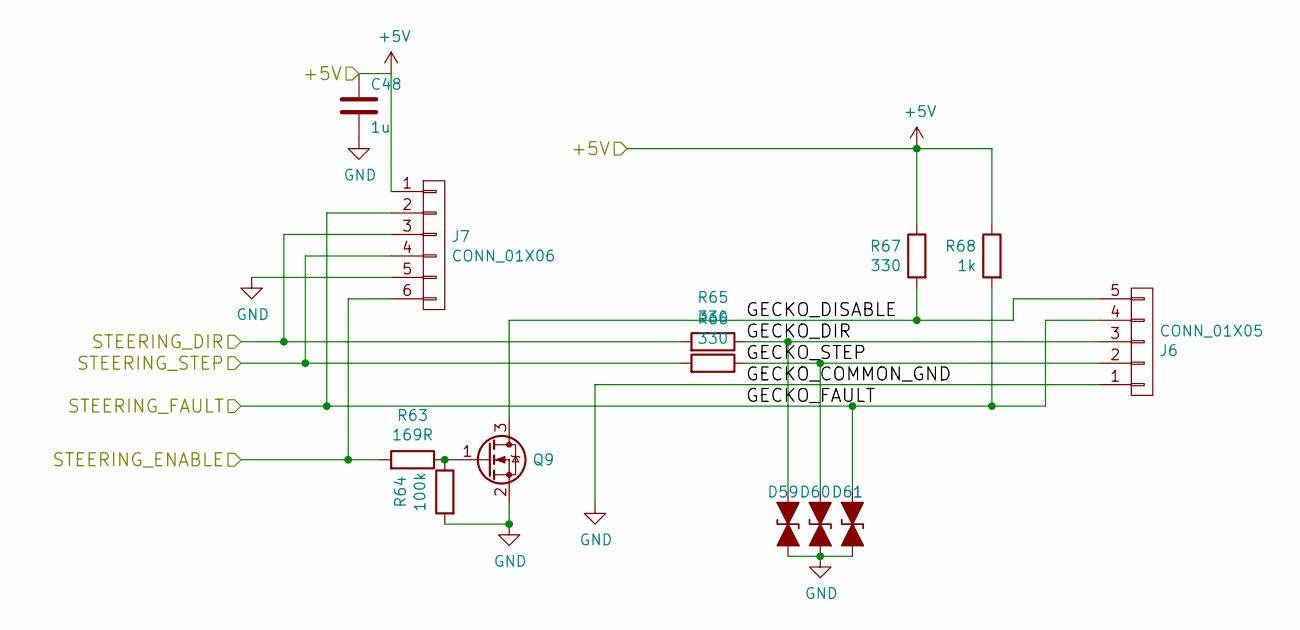
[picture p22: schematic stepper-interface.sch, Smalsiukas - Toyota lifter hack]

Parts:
C48: 1u; C_0603
D59, D60, D61: D_TVS_ALT; SOD-323; PartNo ?
J6: CONN_01X05; TerminalBlock_5.08-5pol; PartNo ?
J7: CONN_01X06; Socket_Strip_Straight_1x06_Pitch2.54mm; PartNo ?
Q9: Q_NMOS_GSD; SOT-23_Handsoldering
R63: 169R; R_0603_HandSoldering; PartNo ?
R64: 100k; R_0603_HandSoldering; PartNo ?
R65, R66, R67: 330; R_0603_HandSoldering; PartNo ?
R68: 1k; R_0603_HandSoldering; PartNo ?

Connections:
+5V: C48.1, J7.1, R67.1, R68.1; also elsewhere on the board
/STEERING_DIR: J7.3, R65.2; also elsewhere on the board
/STEERING_ENABLE: J7.6, R63.2; also elsewhere on the board
/STEERING_FAULT: D61.1 (A1), J6.4, J7.2, R68.2; also elsewhere on the board
/STEERING_STEP: J7.4, R66.2; also elsewhere on the board
/Stepper Interface/GECKO_DIR: D59.1 (A1), J6.3, R65.1
/Stepper Interface/GECKO_DISABLE: J6.5, Q9.3 (D), R67.2
/Stepper Interface/GECKO_STEP: D60.1 (A1), J6.2, R66.1
GND: C48.2, D59.2 (A2), D60.2 (A2), D61.2 (A2), J6.1, J7.5, Q9.2 (S), R64.2; also elsewhere on the board
unnamed: Q9.1 (G), R63.1, R64.1

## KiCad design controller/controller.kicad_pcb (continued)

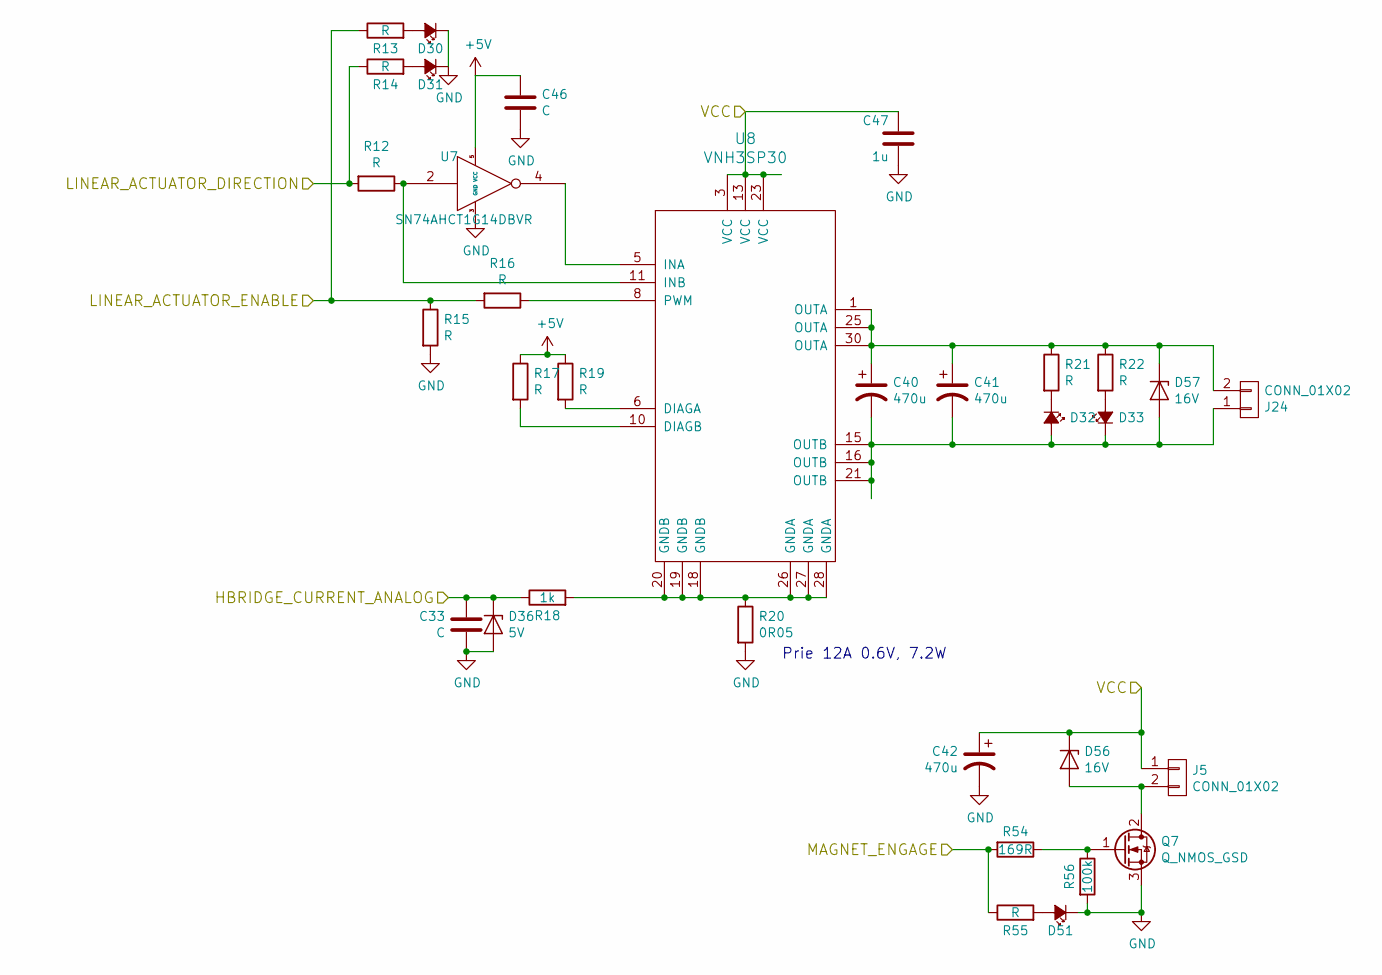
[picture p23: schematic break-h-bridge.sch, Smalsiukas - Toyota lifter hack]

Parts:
C33, C46: C; C_0603_HandSoldering
C40, C41, C42: 470u; CP_Radial_D16.0mm_P7.50mm; PartNo ECA2AAM471X
C47: 1u; C_1210_HandSoldering; PartNo ?
D30, D31, D32, D33, D51: LED_Small_ALT; LED_D5.0mm; PartNo ?
D36: 5V; SOD-123; PartNo ?
D56, D57: 16V; D_SMB_Handsoldering; PartNo 1SMB5930BT3G
J5, J24: CONN_01X02; TerminalBlock_5.08-2pol; PartNo ?
Q7: Q_NMOS_GSD; TO-252-2Lead; PartNo ?
R12, R13, R14, R15, R16, R17, R19, R21, R22, R55: R; R_0603_HandSoldering
R18: 1k; R_0603_HandSoldering
R20: 0R05; TO-220-2_Vertical; PartNo ?
R54: 169R; R_0603_HandSoldering
R56: 100k; R_0603_HandSoldering
U7: SN74AHCT1G14DBVR; SOT-23-5_HandSoldering; PartNo SN74LVC1G14DBVR
U8: VNH3SP30; SOIC-30; PartNo ?

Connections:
+5V: C46.1, R17.1, R19.1, U7.5 (VCC); also elsewhere on the board
/Break H bridge/MAGNET_ENGAGE: R54.2, R55.1; also elsewhere on the board
/HBRIDGE_CURRENT_ANALOG: C33.1, D36.1 (K), R18.1; also elsewhere on the board
/LINEAR_ACTUATOR_DIRECTION: R13.1, R15.1, R16.2; also elsewhere on the board
/LINEAR_ACTUATOR_ENABLE: R12.2, R14.1; also elsewhere on the board
GND: C33.2, C42.2, C46.2, C47.2, D30.1 (K), D31.1 (K), D36.2 (A), D51.1 (K), Q7.3 (S), R15.2, R20.2, R56.2, U7.3 (GND); also elsewhere on the board
unnamed: C40.1, C41.1, D57.1 (K), J24.2, R21.1, R22.1, U8.1 (OUTA), U8.25 (OUTA), U8.30 (OUTA), U8.31
unnamed: C40.2, C41.2, D32.2 (A), D33.1 (K), D57.2 (A), J24.1, U8.15 (OUTB), U8.16 (OUTB), U8.21 (OUTB), U8.32
unnamed: D30.2 (A), R13.2
unnamed: D31.2 (A), R14.2
unnamed: D32.1 (K), R21.2
unnamed: D33.2 (A), R22.2
unnamed: D51.2 (A), R55.2
unnamed: D56.2 (A), J5.2, Q7.2 (D)
unnamed: Q7.1 (G), R54.1, R56.1
unnamed: R12.1, U7.2, U8.11 (INB)
unnamed: R16.1, U8.8 (PWM)
unnamed: R17.2, U8.10 (DIAGB)
unnamed: R18.2, R20.1, U8.18 (GNDB), U8.19 (GNDB), U8.20 (GNDB), U8.26 (GNDA), U8.27 (GNDA), U8.28 (GNDA)
unnamed: R19.2, U8.6 (DIAGA)
unnamed: U7.4, U8.5 (INA)
VCC: C42.1, C47.1, D56.1 (K), J5.1, U8.3 (VCC), U8.13 (VCC), U8.23 (VCC), U8.33; also elsewhere on the board

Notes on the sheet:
Prie 12A 0.6V, 7.2W

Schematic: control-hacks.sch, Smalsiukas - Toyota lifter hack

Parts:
C23, C24, C25, C26, C27, C28, C29, C30, C31: C; C_0603_HandSoldering
C43: 470u; CP_Radial_D16.0mm_P7.50mm; PartNo ECA2AAM471X
C44: 1u; C_1210_HandSoldering; PartNo ?
D18, D19, D20, D21, D22, D23, D24, D25, D26: D_ALT; D_SOD-123
D58: 16V; D_SMB_Handsoldering; PartNo 1SMB5930BT3G
K18, K19, K20, K21, K22, K23, K24, K25, K26: RELAY_SEPARATED; Relay_SPDT; PartNo ?

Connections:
/Control Switching/~AUX_ENABLE_PWR: C31.2, D26.2 (A), K26.1; also elsewhere on the board
/Control Switching/~DIR_BACK_ENABLE_PWR: C24.2, D19.2 (A), K19.10; also elsewhere on the board
/Control Switching/~DIR_FWD_ENABLE_PWR: C23.2, D18.2 (A), K18.10; also elsewhere on the board
/Control Switching/~HORN_ENABLE_PWR: C25.2, D20.2 (A), K20.10; also elsewhere on the board
/Control Switching/~KEY_ENABLE_PWR: C28.2, D23.2 (A), K23.1; also elsewhere on the board
/Control Switching/~LIGHTS_ENABLE_PWR: C29.2, D24.2 (A), K24.1; also elsewhere on the board
/Control Switching/~MIRGALKE_ENABLE_PWR: C30.2, D25.2 (A), K25.1; also elsewhere on the board
/Control Switching/~PARKING_DISABLE_PWR: C26.2, D21.2 (A), K21.10; also elsewhere on the board
/Control Switching/~SEAT_ENABLE_PWR: C27.2, D22.2 (A), K22.10; also elsewhere on the board
/ControlHacks/AUX_COMMON: K26.3; also elsewhere on the board
/ControlHacks/AUX_HACK: K26.4; also elsewhere on the board
/ControlHacks/DIR_SW_BACK_HACK: K19.4; also elsewhere on the board
/ControlHacks/DIR_SW_FWD_HACK: K18.4; also elsewhere on the board
/ControlHacks/HORN_SW_HACK: K20.4; also elsewhere on the board
/ControlHacks/KEY_COLD_HACK: K23.4; also elsewhere on the board
/ControlHacks/KEY_HOT_HACK: K23.3; also elsewhere on the board
/ControlHacks/LIGHTS_COMMON: K24.3, K25.3; also elsewhere on the board
/ControlHacks/LIGHTS_HACK: K24.4; also elsewhere on the board
/ControlHacks/MIRGALKE_HACK: K25.4; also elsewhere on the board
/ControlHacks/PARKING_HACK: K21.4; also elsewhere on the board
/ControlHacks/SEAT_GND_HACK: K22.4; also elsewhere on the board
/ControlHacks/SEAT_HACK: K22.3; also elsewhere on the board
/ControlHacks/STEERING_COMMON: K18.3, K19.3, K20.3, K21.3; also elsewhere on the board
/Power/+5V_DIRTY: C23.1, C24.1, C25.1, C26.1, C27.1, C28.1, C29.1, C30.1, C31.1, C43.1, C44.2, D18.1 (K), D19.1 (K), D20.1 (K), D21.1 (K), D22.1 (K), D23.1 (K), D24.1 (K), D25.1 (K), D26.1 (K), D58.1 (K), K18.1, K19.1, K20.1, K21.1, K22.1, K23.10, K24.10, K25.10, K26.10; also elsewhere on the board
GND: C43.2, C44.1, D58.2 (A); also elsewhere on the board

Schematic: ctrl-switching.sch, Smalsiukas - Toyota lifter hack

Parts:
C45: 1u; C_0603_HandSoldering
D35, D37, D38, D39, D42, D43, D44, D45, D46, D47, D48, D49, D50: LED_Small_ALT; LED_D5.0mm; PartNo ?
R23, R24, R25, R26, R28, R29, R30, R32, R33, R34, R35, R36, R37, R38, R39, R40, R41, R69, R70, R71, R72, R73, R74, R75, R76, R77, R78, R79, R80, R81, R82, R83: R; R_0603_HandSoldering
U9: 74HC595_WITH_PWR; SOIC-16_3.9x9.9mm_Pitch1.27mm; PartNo ?
U10, U11: ULN2803A; SOIC-18W_7.5x11.6mm_Pitch1.27mm; PartNo ?

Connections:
+5V: C45.1, U9.10 (SRCLR), U9.16 (VCC); also elsewhere on the board
/Control Switching/AUX_ENABLE: R80.2, U9.5 (QF), U11.6 (I6)
/Control Switching/DIR_BACK_ENABLE: R83.2, U9.7 (QH), U11.8 (I8)
/Control Switching/DIR_FWD_ENABLE: R82.2, U9.6 (QG), U11.7 (I7)
/Control Switching/GAZ_ENABLE: R69.2, U10.2 (I2); also elsewhere on the board
/Control Switching/HORN_ENABLE: R70.2, U9.15 (QA), U11.1 (I1)
/Control Switching/KEY_ENABLE: R32.2, U10.1 (I1); also elsewhere on the board
/Control Switching/LIGHTS_ENABLE: R76.2, U9.3 (QD), U11.4 (I4)
/Control Switching/MIRGALKE_ENABLE: R78.2, U9.4 (QE), U11.5 (I5)
/Control Switching/PARKING_DISABLE: R72.2, U9.1 (QB), U11.2 (I2)
/Control Switching/SEAT_ENABLE: R74.2, U9.2 (QC), U11.3 (I3)
/Control Switching/~AUX_ENABLE_PWR: D48.1 (K), U11.13 (O6); also elsewhere on the board
/Control Switching/~DIR_BACK_ENABLE_PWR: D44.1 (K), U11.15 (O4); also elsewhere on the board
/Control Switching/~DIR_FWD_ENABLE_PWR: D43.1 (K), U11.14 (O5); also elsewhere on the board
/Control Switching/~GAZ_ENABLE_PWR: D42.1 (K), U10.17 (O2); also elsewhere on the board
/Control Switching/~GAZ_SPEED1_PWR: D39.1 (K), U10.14 (O5); also elsewhere on the board
/Control Switching/~GAZ_SPEED2_PWR: D38.1 (K), U10.15 (O4); also elsewhere on the board
/Control Switching/~GAZ_SPEED3_PWR: D37.1 (K), U10.16 (O3); also elsewhere on the board
/Control Switching/~HORN_ENABLE_PWR: D45.1 (K), U11.16 (O3); also elsewhere on the board
/Control Switching/~KEY_ENABLE_PWR: D35.1 (K), U10.18 (O1); also elsewhere on the board
/Control Switching/~LIGHTS_ENABLE_PWR: D50.1 (K), U11.11 (O8); also elsewhere on the board
/Control Switching/~MIRGALKE_ENABLE_PWR: D49.1 (K), U11.12 (O7); also elsewhere on the board
/Control Switching/~PARKING_DISABLE_PWR: D46.1 (K), U11.17 (O2); also elsewhere on the board
/Control Switching/~SEAT_ENABLE_PWR: D47.1 (K), U11.18 (O1); also elsewhere on the board
/GAZ_SPEED1: R75.2, U10.5 (I5); also elsewhere on the board
/GAZ_SPEED2: R73.2, U10.4 (I4); also elsewhere on the board
/GAZ_SPEED3: R71.2, U10.3 (I3); also elsewhere on the board
/Power/+5V_DIRTY: R26.1, R28.1, R29.1, R30.1, R33.1, R34.1, R35.1, R36.1, R37.1, R38.1, R39.1, R40.1, R41.1, U10.10 (COM), U11.10 (COM); also elsewhere on the board
/SPI_CLK: R24.2; also elsewhere on the board
/SPI_DATA: R23.2; also elsewhere on the board
/SPI_LATCH: R25.2; also elsewhere on the board
GND: C45.2, R32.1, R69.1, R70.1, R71.1, R72.1, R73.1, R74.1, R75.1, R76.1, R77.1, R78.1, R79.1, R80.1, R81.1, R82.1, R83.1, U9.8 (GND), U9.13 (G), U10.9 (GND), U11.9 (GND); also elsewhere on the board
unnamed: D35.2 (A), R26.2
unnamed: D37.2 (A), R28.2
unnamed: D38.2 (A), R29.2
unnamed: D39.2 (A), R30.2
unnamed: D42.2 (A), R33.2
unnamed: D43.2 (A), R34.2
unnamed: D44.2 (A), R35.2
unnamed: D45.2 (A), R36.2
unnamed: D46.2 (A), R37.2
unnamed: D47.2 (A), R38.2
unnamed: D48.2 (A), R39.2
unnamed: D49.2 (A), R40.2
unnamed: D50.2 (A), R41.2
unnamed: R23.1, U9.14 (SER)
unnamed: R24.1, U9.11 (SRCLK)
unnamed: R25.1, U9.12 (RCLK)
unnamed: R77.2, U10.6 (I6)
unnamed: R79.2, U10.7 (I7)
unnamed: R81.2, U10.8 (I8)

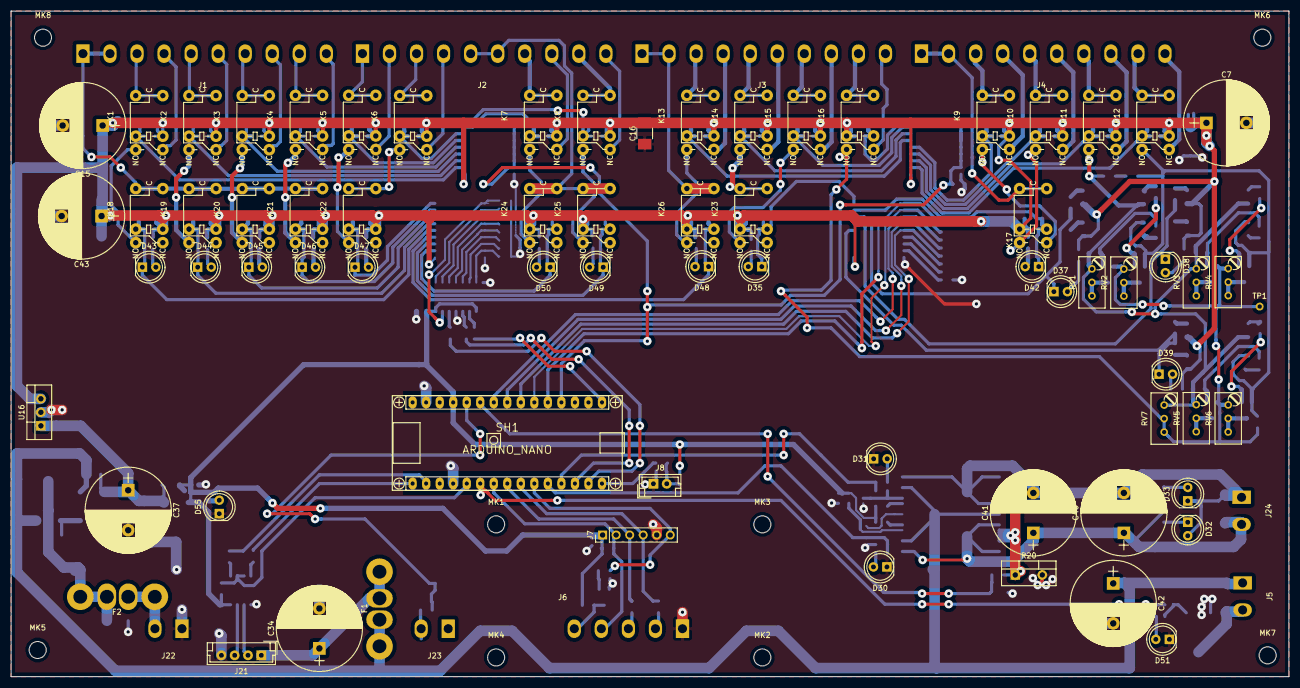
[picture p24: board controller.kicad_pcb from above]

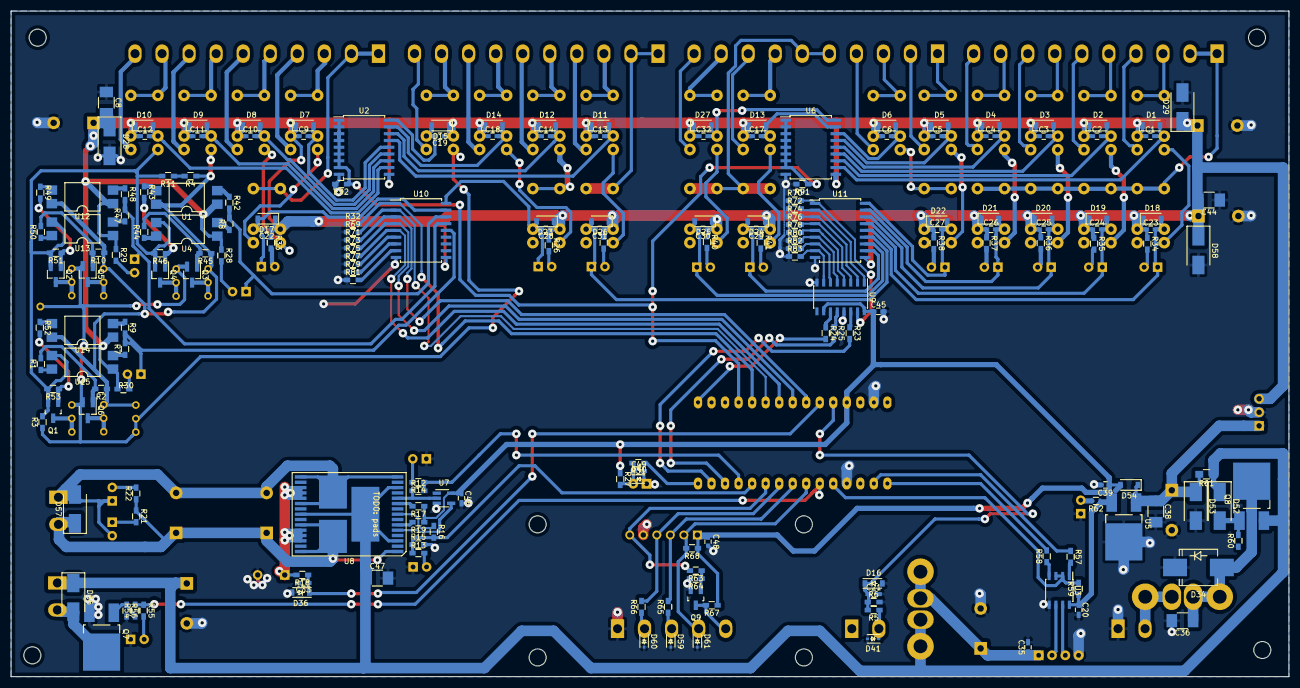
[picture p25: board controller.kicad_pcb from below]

Board: 2 copper layers, 240.0 x 125.0 mm, 277 parts (190 on the bottom side), 190 nets.

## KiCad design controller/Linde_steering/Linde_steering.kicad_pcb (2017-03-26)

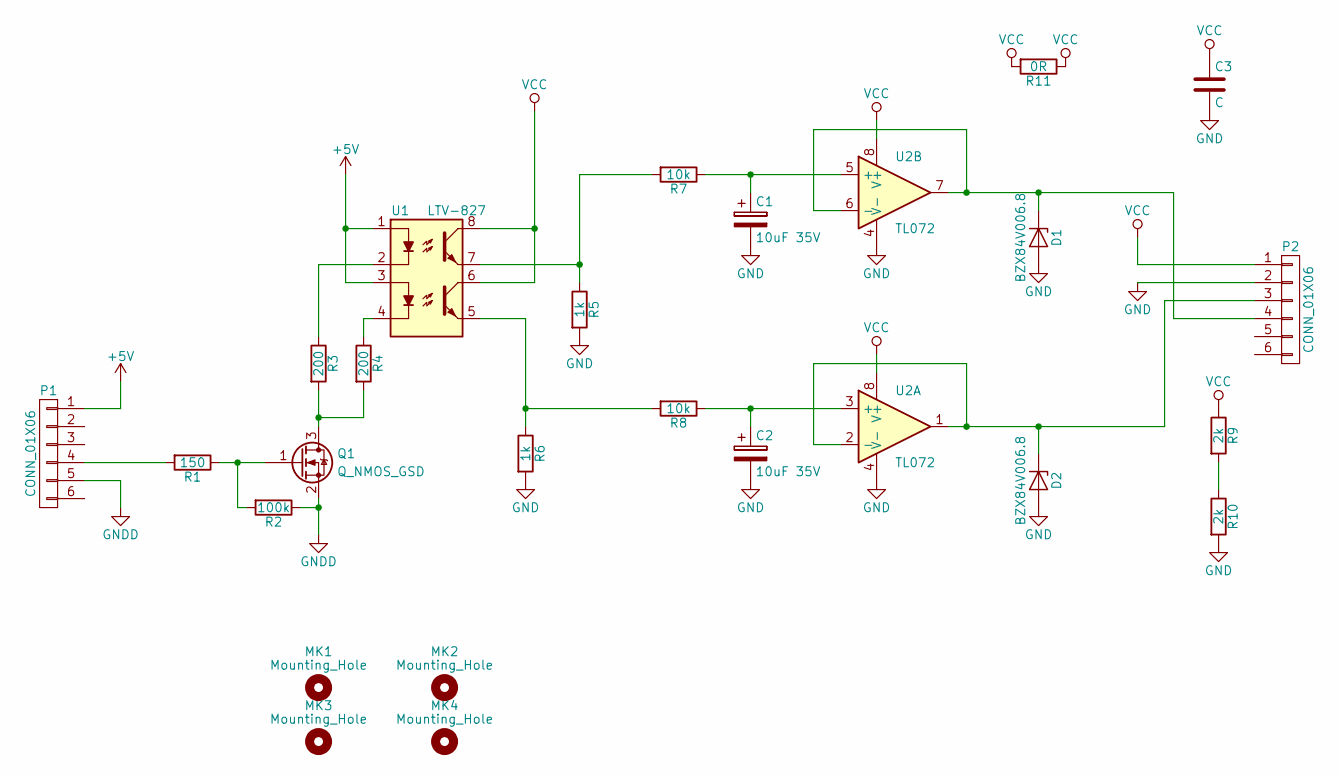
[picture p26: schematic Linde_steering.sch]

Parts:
C1, C2: 10uF 35V; CP_Elec_5x5.7
C3: C; R_1206_HandSoldering
D1, D2: BZX84V006.8; SOT-23
MK1, MK2, MK3, MK4: Mounting_Hole; MountingHole_3.2mm_M3_Pad
P1: CONN_01X06; Socket_Strip_Straight_1x06_Pitch2.54mm
P2: CONN_01X06; TerminalBlock_5.08-6pol
Q1: Q_NMOS_GSD
R1: 150; R_0805_HandSoldering
R2: 100k; R_0805_HandSoldering
R3, R4: 200; R_0805_HandSoldering
R5, R6: 1k; R_0805_HandSoldering
R7, R8: 10k; R_0805_HandSoldering
R9, R10: 2k; R_0805_HandSoldering
R11: 0R; R_0805_HandSoldering
U1: LTV-827; DIP-8_SMD
U2: TL072; SOIC-8-N

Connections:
+5V: P1.1, U1.1, U1.3
GND: C1.2, C2.2, C3.2, D1.1 (A), D2.1 (A), P2.2, R5.2, R6.2, R10.2, U2.4 (V-)
GNDD: P1.5, Q1.2 (S), R2.1
unnamed: C1.1, R7.1, U2.5 (+)
unnamed: C2.1, R8.1, U2.3 (+)
unnamed: D1.3 (K), P2.4, U2.6 (-), U2.7
unnamed: D2.3 (K), P2.3, U2.1, U2.2 (-)
unnamed: P1.4, R1.2
unnamed: Q1.1 (G), R1.1, R2.2
unnamed: Q1.3 (D), R3.2, R4.2
unnamed: R3.1, U1.2
unnamed: R4.1, U1.4
unnamed: R5.1, R7.2, U1.7
unnamed: R6.1, R8.2, U1.5
unnamed: R9.2, R10.1
VCC: C3.1, P2.1, R9.1, R11.1, R11.2, U1.6, U1.8, U2.8 (V+)

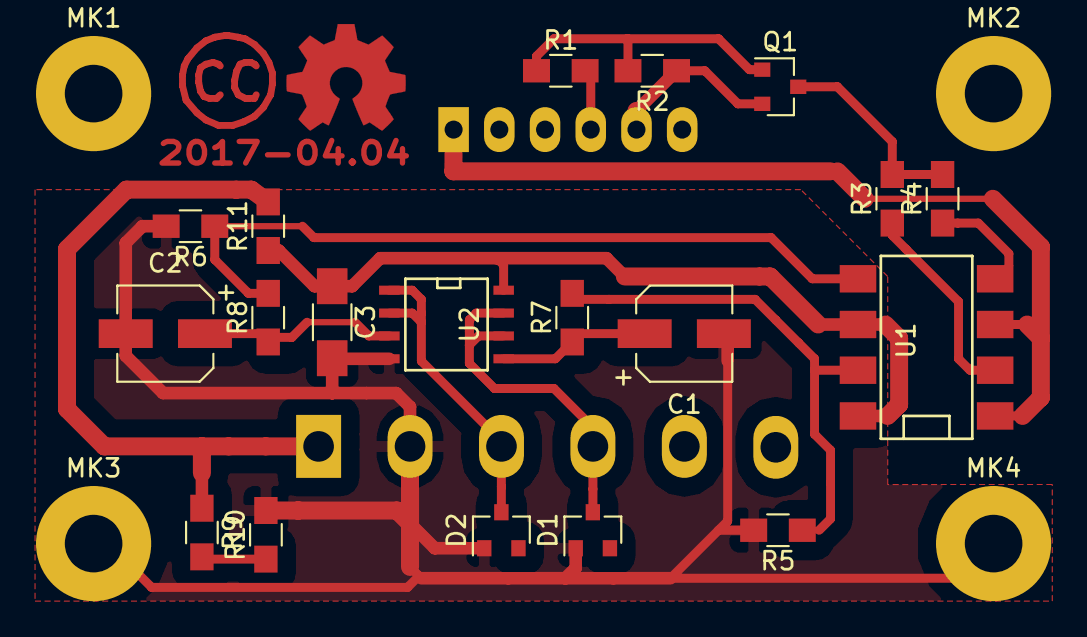
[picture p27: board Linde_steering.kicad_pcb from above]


Board: 2 copper layers, 25 parts (2 on the bottom side), 16 nets.

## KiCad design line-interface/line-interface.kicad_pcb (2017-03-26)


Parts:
C1, C4, C7, C9: 1u; C_0603
C2, C5: 1u; C_1210_HandSoldering; PartNo ?
C3: CP1; CP_Radial_D8.0mm_P3.50mm; PartNo ?
C6, C8: 18p; C_0603
D1: D_TVS_ALT; Diode-SMC_Handsoldering; PartNo 1.5SMCJ48CA
D2: 60V; D_SMB_Handsoldering; PartNo 1SMB5944BT3G
D3: 15V; SOD-123; PartNo KDZVTR15B
D4, D6: GREEN; LED_0603; PartNo ?
D7: D; D_SOD-123; PartNo ?
IC1: ATTINY441-SSU; SOIC-14_3.9x8.7mm_Pitch1.27mm; PartNo ?
J1: CONN_01X06; Pin_Header_Straight_1x06_Pitch2.54mm; PartNo ?
MK1, MK2, MK3, MK4: Mounting_Hole; MountingHole_3.2mm_M3; PartNo ?
P1: CONN_02X03; Pin_Header_Straight_2x03_Pitch2.54mm; PartNo ?
P2: CONN_01X04; Pin_Header_Straight_1x04_Pitch2.54mm; PartNo ?
Q1: NDT2955; TO-252-2Lead; PartNo IRFR5410TRPBF
R1: 10; R_2512; PartNo ?
R2, R3, R4, R6, R9, R10: 10k; R_0603
R8: 330; R_0603
U1: LM7805CT; TO-220_Horizontal; PartNo ?
U2: SN65HVD72; SOIC-8_3.9x4.9mm_Pitch1.27mm; PartNo MAX13442EASA
X1: 16MHz; Crystal_HC49-SD_SMD

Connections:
+5V: C1.1, C7.1, C9.1, D7.2 (A), IC1.1 (VCC), J1.5, P1.2, R4.2, R8.1, U1.3 (OUT), U2.8 (VCC)
/CLOCK: J1.3, R9.2
/MISO: IC1.8 ((PCINT5/MISO/TXD1/T2/TOCC4/ACO0/ADC5)PA5), P1.1, R6.1
/MOSI: IC1.7 ((PCINT6/MOSI/SDA/XCK1/TOCC5/ACO1/ADC6)P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), P1.4
/RESET: C4.1, IC1.4 ((PCINT11/dW/~RESET~/ADC9)PB3), P1.5, R4.1
/RS485A: P2.3, U2.6 (A)
/RS485B: P2.2, U2.7 (B)
/SCK: IC1.9 ((PCINT4/SCK/SCL/RXD1/T1/TOCC3/AIN11/ADC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), P1.3, R9.1
/SERIAL_DATA_IN: J1.2, R6.2
/~CS: IC1.6 ((PCINT7/~SS~/TXD0/ICP1/TOCC6/ADC7)PA7), R10.1
/~LOAD: J1.4, R10.2
GND: C1.2, C2.2, C3.2, C4.2, C5.2, C6.2, C7.2, C8.2, C9.2, D1.2 (A2), D2.2 (A), D4.1 (K), D6.1 (K), IC1.14 (GND), J1.1, J1.6, P1.6, P2.4, R2.1, U1.2 (GND), U2.5 (GND)
unnamed: C2.1, D2.1 (K), Q1.2 (D), R1.2
unnamed: C3.1, C5.1, D3.1 (K), D7.1 (K), Q1.3 (S), U1.1 (IN)
unnamed: C6.1, IC1.3 ((PCINT9/INT0/XTAL2/ADC10)PB1), X1.1
unnamed: C8.1, IC1.2 ((PCINT8/CLKI/XTAL1/ADC11)PB0), X1.2
unnamed: D3.2 (A), Q1.1 (G), R2.2
unnamed: D4.2 (A), R3.1
unnamed: D6.2 (A), R8.2
unnamed: IC1.10 ((PCINT3/SCK/XCK0/T0/TOCC2/AIN10/ADC3)PA3), R3.2
unnamed: IC1.11 ((PCINT2/~SS~/RXD0/TOCC1/AIN01/ADC2)PA2), U2.1 (RO)
unnamed: IC1.12 ((PCINT1/MOSI/TXD0/TOCC0/AIN00/ADC1)PA1), U2.4 (DI)
unnamed: IC1.13 ((PCINT0/MISO/AREF/ADC0)PA0), U2.2 (~RE~), U2.3 (DE)
VCC: D1.1 (A1), P2.1, R1.1


Board: 2 copper layers, 52.0 x 49.0 mm, 35 parts (1 on the bottom side), 24 nets.

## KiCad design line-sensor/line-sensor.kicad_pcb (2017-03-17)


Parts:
C1, C2, C3, C4, C5: C; C_0603_HandSoldering; PartNo ?
J1: CONN_01X10; Multicomp_MC9A12-1034_2x05x2.54mm_Straight; PartNo ?
J2: IN; Pin_Header_Straight_1x06_Pitch2.54mm; PartNo ?
J3: OUT; Pin_Header_Straight_1x06_Pitch2.54mm; PartNo ?
R1, R2, R3, R4, R5, R6, R7, R8, R9, R10, R11, R12, R13, R14, R15, R16, R17, R18, R19, R20, R21, R22, R23, R24, R25, R26, R27, R28, R29, R30, R31, R32: R; R_0603_HandSoldering; PartNo ?
RV1, RV2, RV3, RV4, RV5, RV6, RV7, RV8, RV9: POT; Potentiometer_Trimmer_Bourns_3006W; PartNo ?
U1: LM358; SOIC-8_3.9x4.9mm_Pitch1.27mm; PartNo ?
U2: CNY70; DIP-4_W7.62mm_LongPads; PartNo CNY70
U3, U4, U5, U6, U7, U8, U9: CNY70; DIP-4_W7.62mm; PartNo CNY70
U10, U11: LM339; SOIC-14_3.9x8.7mm_Pitch1.27mm; PartNo ?
U12: 74LS165-; SOIC-16_3.9x9.9mm_Pitch1.27mm; PartNo ?
U13: ULN2801A; SOIC-18W_7.5x11.6mm_Pitch1.27mm; PartNo ?

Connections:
+5V: C2.1, C3.1, C4.1, C5.1, J2.5, J3.5, R17.2, R18.2, R19.2, R20.2, R21.2, R22.2, R23.2, R24.2, RV1.1, U1.8 (V+), U2.1, U2.4, U3.1, U3.4, U4.1, U4.4, U5.1, U5.4, U6.1, U6.4, U7.1, U7.4, U8.1, U8.4, U9.1, U9.4, U10.3 (V+), U11.3 (V+), U12.16 (VCC)
/CLOCK: J2.3, J3.3, U12.2 (CP)
/SERIAL_DATA_IN: J2.2, U12.10 (Ds)
/SERIAL_DATA_OUT: J3.2, U12.9 (Q7)
/V_REF: R9.2, R10.2, R11.2, R12.2, R13.2, R14.2, R15.2, R16.2, U1.1, U1.2 (-)
/~LOAD: J2.4, J3.4, U12.1 (Pl)
GND: C1.2, C2.2, C3.2, C4.2, C5.2, J2.1, J2.6, J3.1, J3.6, R1.2, R2.2, R3.2, R4.2, R5.2, R6.2, R7.2, R8.2, RV1.3, RV2.2, RV3.1, RV3.2, RV4.1, RV4.2, RV5.1, RV5.2, RV6.1, RV6.2, RV7.1, RV7.2, RV8.1, RV8.2, RV9.1, RV9.2, U1.4 (V-), U10.12 (V-), U11.12 (V-), U12.8 (GND), U12.15 (CE), U13.9 (GND)
unnamed: C1.1, RV1.2, U1.3 (+)
unnamed: J1.1, U13.18 (O1)
unnamed: J1.2, U13.17 (O2)
unnamed: J1.3, U13.16 (O3)
unnamed: J1.4, U13.15 (O4)
unnamed: J1.5, U13.14 (O5)
unnamed: J1.6, U13.13 (O6)
unnamed: J1.7, U13.12 (O7)
unnamed: J1.8, U13.11 (O8)
unnamed: R1.1, U2.2
unnamed: R2.1, U3.2
unnamed: R3.1, U4.2
unnamed: R4.1, U5.2
unnamed: R5.1, U6.2
unnamed: R6.1, U7.2
unnamed: R7.1, U8.2
unnamed: R8.1, U9.2
unnamed: R10.1, R26.2, U10.9 (+)
unnamed: R11.1, R27.2, U10.5 (+)
unnamed: R12.1, R28.2, U10.7 (+)
unnamed: R13.1, R29.2, U11.9 (+)
unnamed: R14.1, R30.2, U11.11 (+)
unnamed: R15.1, R31.2, U11.5 (+)
unnamed: R16.1, R32.2, U11.7 (+)
unnamed: R17.1, R25.1, U10.13, U12.11 (P0), U13.1 (I1)
unnamed: R18.1, R26.1, U10.14, U12.12 (P1), U13.2 (I2)
unnamed: R19.1, R27.1, U10.2, U12.13 (P2), U13.3 (I3)
unnamed: R20.1, R28.1, U10.1, U12.14 (P3), U13.4 (I4)
unnamed: R21.1, R30.1, U11.13, U12.4 (P5), U13.6 (I6)
unnamed: R22.1, R29.1, U11.14, U12.3 (P4), U13.5 (I5)
unnamed: R23.1, R31.1, U11.2, U12.5 (P6), U13.7 (I7)
unnamed: R24.1, R32.1, U11.1, U12.6 (P7), U13.8 (I8)
unnamed: R9.1, R25.2, U10.11 (+)
unnamed: RV2.3, U2.3, U10.10 (-)
unnamed: RV3.3, U3.3, U10.8 (-)
unnamed: RV4.3, U4.3, U10.4 (-)
unnamed: RV5.3, U5.3, U10.6 (-)
unnamed: RV6.3, U6.3, U11.8 (-)
unnamed: RV7.3, U7.3, U11.10 (-)
unnamed: RV8.3, U8.3, U11.4 (-)
unnamed: RV9.3, U9.3, U11.6 (-)



Board: 2 copper layers, 316.0 x 49.0 mm, 62 parts (17 on the bottom side), 48 nets.

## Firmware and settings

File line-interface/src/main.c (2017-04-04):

#include <inttypes.h>
#include <avr/io.h>
#include <util/delay.h>
#include <avr/interrupt.h>
#include <avr/wdt.h>
#include <stdio.h>

#define LED_A PA3
#define LED_DDR DDRA
#define LED_PORT PORTA
#define DRIVER_ENABLE PA0
#define SPI_CS PA7
#define SPI_MOSI PA6
#define SPI_CLK PA4

char lineData = 0;
char lineFiltered = 0;
uint8_t sensors[8];

inline static void serialSetup() {
    #define BAUD 115200
    #include <util/setbaud.h>
    DDRA |= _BV(DRIVER_ENABLE);
    PORTA &= ~_BV(DRIVER_ENABLE);

    UBRR0H = UBRRH_VALUE;
    UBRR0L = UBRRL_VALUE;
    UCSR0A |= _BV(U2X0);
    UCSR0B = _BV(RXEN0) | _BV(TXEN0);
    UCSR0C = _BV(UCSZ00) | _BV(UCSZ01);
}

inline static setupSPI() {
    DDRA |= _BV(SPI_CS) | _BV(SPI_CLK) | _BV(SPI_MOSI);
    PORTA |= _BV(SPI_CS);
    SPCR = _BV(SPE) | _BV(MSTR);
}

inline static uint8_t readSPI() {
    PORTA &= ~_BV(SPI_CS);
    _delay_ms(1);
    PORTA |= _BV(SPI_CS);

    SPDR = 0;
    while(!(SPSR & (1<<SPIF))){
        //wait
    }
    return SPDR;
}

inline static void timerSetup() {
    OCR1A = 20000;
    TIMSK1 = _BV(OCIE1A);
    TCCR1B = _BV(WGM12) | _BV(CS11);
}

inline static void serialDriverEnable() {
    PORTA |= _BV(DRIVER_ENABLE);
}

inline static void serialDriverDisable() {
    PORTA &= ~_BV(DRIVER_ENABLE);
    UCSR0A |= _BV(TXC0);
}

void uart_putchar(char c, FILE *stream) {
    if (c == '\n') {
        uart_putchar('\r', stream);
    }
    loop_until_bit_is_set(UCSR0A, UDRE0);
    UDR0 = c;
}

FILE uart_output = FDEV_SETUP_STREAM(uart_putchar, NULL, _FDEV_SETUP_WRITE);


inline static void ledSetup(){
    LED_DDR |= _BV(LED_A);
    LED_PORT &= ~_BV(LED_A);
}

inline static void ledOn() {
    LED_PORT |= _BV(LED_A);
}

inline static void ledOff() {
    LED_PORT &= ~_BV(LED_A);
}

inline static ledToggle() {
    LED_PORT ^= _BV(LED_A);
}

inline static outputBits(char c) {
    uint8_t i;
    for(i = 0; i < 8; i++) {
        if(0 != (0b10000000 & c)) {
            uart_putchar('1', stdout);
        } else {
            uart_putchar('0', stdout);
        }
        c = c << 1;
    }
    uart_putchar('\n', stdout);
}

inline static outputSensors() {
    uint8_t i;
    for(i = 0; i < 8; i++) {
        if(sensors[i] == 255) {
            uart_putchar('1', stdout);
        } else {
            uart_putchar('0', stdout);
        }
    }    
    uart_putchar('\n', stdout);
}

inline static void filter(uint8_t line) {
    uint8_t i;
    for(i = 0; i < 8;i++) {
        sensors[i] = (sensors[i] << 1) | (0 != (line & _BV(i)));
        if(lineFiltered & _BV(i) && 0 == sensors[i]) {
            lineFiltered &= ~_BV(i);
        } else if(0 == (lineFiltered & _BV(i)) && 255 == sensors[i]) {
            lineFiltered |= _BV(i);
        }
    }
}

volatile uint8_t doScan = 0;

ISR(TIMER1_COMPA_vect) {
    doScan = 1;
}

inline static uint8_t isRequest() {
    return (_BV(RXC0) & UCSR0A) && '?' == UDR0;
}

inline static uint8_t isTxDone() {
    return (_BV(TXC0) & UCSR0A);
}

int main (void) {
    wdt_disable();

    ledSetup();
    stdout = &uart_output;
    serialSetup();
    setupSPI();
    timerSetup();
    sei();

    while(1) {
        if(doScan) {
            lineData = readSPI();
            filter(lineData);
            doScan = 0;
        }
        if(isRequest()) {
            ledOn();
            serialDriverEnable();
            _delay_us(200);
            uart_putchar(lineFiltered, stdout);
            uart_putchar(~lineFiltered + 1, stdout);
        }else{
            if(isTxDone()) {
                serialDriverDisable();
                ledOff();
            }
        }
    }
}

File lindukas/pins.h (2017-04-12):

#ifndef __PINS_H
#define __PINS_H

#define RS458_DE_RD 				2
//#define MAGNET_ENGAGE 				3
//#define STEERING_FAULT 				4
//#define STEERING_DIR 				5
//#define STEERING_STEP 				6
//#define STEERING_ENABLE 			7

#define STEERING_PIN_YELLOW 5
#define STEERING_PIN_GREY 6

#define BUTTON_START      4

//#define LINEAR_ACTUATOR_DIRECTION 	9

#define SERVO_PIN 9
#define GAZ_PWM_PIN 3

//#define LINEAR_ACTUATOR_ENABLE 		8
#define SPI_LATCH 					10
#define SPI_DATA 					11
//#define RANGEFINDER_WARNING 		12
#define SPI_CLK 					13
#define TAKEOVER 					A0
//#define KEY_ENABLE					A1
//#define GAZ_ENABLE					A2
//#define GAZ_SPEED1 					A3
//#define GAZ_SPEED2 					A4
//#define GAZ_SPEED3 					A5 

//#define HBRIDGE_CURRENT_ANALOG 		A6
//#define WHEEL_POS_ANALOG 			A7

void pinsInit() {
	pinMode(TAKEOVER 					, OUTPUT);
	pinMode(RS458_DE_RD 				, OUTPUT);
	pinMode(SPI_LATCH 					, OUTPUT);
	digitalWrite(SPI_LATCH, LOW);
	pinMode(SPI_DATA 					, OUTPUT);
	pinMode(SPI_CLK 					, OUTPUT);
	
	pinMode(STEERING_PIN_YELLOW  		, OUTPUT);
	pinMode(STEERING_PIN_GREY			, OUTPUT);
//	pinMode(SERVO_PIN					, OUTPUT);
  pinMode(GAZ_PWM_PIN          , OUTPUT);
	pinMode(BUTTON_START				, INPUT_PULLUP);
}


#endif

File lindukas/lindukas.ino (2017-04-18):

#define USE_GAZ_PWM 1

#include "pins.h"

#ifndef USE_GAZ_PWM
#include "Servo.h"
#endif

#include "lindukas.h"
#include "steering.h"
#include "line_follower.h"
#include "Bounce2.h"
#include "control.h"


Bounce button = Bounce();


//#include "gaz.h"
uint32_t lineLastSeenTs = 0;

void setup() {
  sendControl();

  Serial.begin(115200);
  Serial.println("Hello");

  control = control | LED_STAGE_1;
  sendControl();

  pinsInit();
#ifdef __GAZ_H
  speedServo.attach(SERVO_PIN);
#endif

  // center gaz pot
  gazDisable();


  button.attach(BUTTON_START);
  button.interval(100);

  steeringInit();
  controlTakeover();


  // show 2 LEDs
  control = control | LED_STAGE_1 | LED_STAGE_2 | LED_STAGE_3 | LED_STAGE_4;
  sendControl();
  
  delay(6000);

// wait for button

  while (!button.fell()) {
    control = control & ~LED_STAGE_3;
    sendControl();
    delay(100);
    control = control | LED_STAGE_3;
    sendControl();
    delay(100);
    button.update();
  }
    // all LEDs off...
    control = control & ~LED_STAGE_1 & ~LED_STAGE_2 & ~LED_STAGE_3 & ~LED_STAGE_4;
    sendControl();
    gazInit();
    smalsiukasState = STATE_FOLLOWING;
    delay(200);
    beep();
    
    go();
    button.update();
    lineLastSeenTs = millis();
    
}

//koeficientas, kiek pasukti ratus esant kokiam nuokrypiui
#define P 4
uint8_t nonCriticalSteerings = 0;
uint8_t steerings = 0;

void followTheLine() {
  switch (smalsiukasState) {
    case STATE_STOP:
      if (button.fell()) {
        go();
        smalsiukasState = STATE_FOLLOWING;
        beep();
        lineLastSeenTs = millis();
      }
      break;
    case STATE_FOLLOWING:
      if (isTimeToSteer()) {
        if (isLineAvailable()) {
          uint8_t l = getLine();
          if (isLineDetected(l)) {
            lineLastSeenTs = millis();
            if (l != lastLine) {
              lastLine = l;
              steerings ++;

              if (firstSteering && !steeringIsMoveDone()) {
                steeringRunToPosition();
                firstSteering = 0;
              }

              if (isLineCritical(l)) {
                nonCriticalSteerings = 0;
                setSpeed(SPEED1);
              } else {
                setSpeed(SPEED2);
                nonCriticalSteerings++;
                // if(nonCriticalSteerings > 0 && steerings > 35) {
                // 	stop();
                // 	delay(500);
                // 	go();
                // 	steerings = 0;
                // 	nonCriticalSteerings = 0;
                // 	lastLine = 0;
                // 	firstSteering = 1;
                // 	lineLastSeenTs = millis();
                // }
              }
              int16_t steer = getErrorAngle(line) * P;
              //							Serial.println(steer);
              steeringSetAngle(steer);
              steeringRunToPosition();
            }
            mirgalkeOff();
          } else {
          }
        } else if (isRequestTimeout()) {
          Serial.print('T');
          delay(100);
        } else if (isChecksumError()) {
          Serial.println('!');
          delay(100);
        } else {
          mirgalkeOn();
        }
      }

      if (button.fell()) {
        stop();
        smalsiukasState = STATE_STOP;
      }

		if (millis() - lineLastSeenTs > LINE_SEEN_TIMEOUT) {
		  parkingOn();
		  beeep();
		  delay(500);
		  beeep();
		  stop();
		  smalsiukasState = STATE_STOP;
		}

      break;
    case STATE_ERROR:
      break;
  }
}

int8_t turnTo = 90;

void loop() {
  followTheLine();

  steeringRun();
  button.update();
}

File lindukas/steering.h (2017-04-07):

#ifndef __STEERING_H
#define __STEERING_H

#include "pins.h"

/*
90° prie 68

75/90 * 1024
*/
#define STEPS_PER_DEGREE 773


uint16_t backlash = 175;
uint8_t noFeedback = 0;
uint16_t nextPosition = 0;
uint8_t nextPositionScheduled = 0;



#define STEERING_PIN_GREY_OFFSET (118 - 128)
#define STEERING_PIN_YELLOW_OFFSET (138 - 128)

#define STEERING_PIN_YELLOW_MAX_VALUE (200 + STEERING_PIN_YELLOW_OFFSET)
#define STEERING_PIN_GREY_MAX_VALUE (200 + STEERING_PIN_GREY_OFFSET)

#define STEERING_PIN_YELLOW_MIN_VALUE (20 - STEERING_PIN_YELLOW_OFFSET)
#define STEERING_PIN_GREY_MIN_VALUE (20 - STEERING_PIN_GREY_OFFSET)

#define TURN_PERIOD_MS 15

typedef enum{
  Direction_CW,
  Direction_CCW
  } Direction_t;

Direction_t direction = Direction_CW;

//STEERING_PIN_GREY STEERING_PIN_YELLOW
uint8_t center[] = {128 + STEERING_PIN_GREY_OFFSET, 128 + STEERING_PIN_YELLOW_OFFSET};
uint8_t curPos = 128;

uint8_t isTurning = 0;
uint8_t setPos = 128;

uint32_t lastTurnTs = 0;

uint8_t isTimeToTurnTheWheel() {
  return millis() - lastTurnTs >= TURN_PERIOD_MS; 
}


void lindeSteerTo(uint16_t targetPosition) {
    if(targetPosition > STEERING_PIN_GREY_MAX_VALUE) {
      targetPosition = STEERING_PIN_GREY_MAX_VALUE;
    }
    
    if(targetPosition > STEERING_PIN_YELLOW_MAX_VALUE) {
      targetPosition = STEERING_PIN_YELLOW_MAX_VALUE;
    }

    if(targetPosition < STEERING_PIN_GREY_MIN_VALUE) {
      targetPosition = STEERING_PIN_GREY_MIN_VALUE;
    }
    
    if(targetPosition < STEERING_PIN_YELLOW_MIN_VALUE) {
      targetPosition = STEERING_PIN_YELLOW_MIN_VALUE;
    }

    
    if(targetPosition > curPos) {
      Serial.println("CW");
      direction = Direction_CW;
      setPos = targetPosition;
      isTurning = 1;
    } else if(targetPosition < curPos) {
      Serial.println("CCW");
      direction = Direction_CCW;
      setPos = targetPosition;
      isTurning = 1;    
    } else {
      isTurning = 0;
    }
    Serial.print("go to: ");
    Serial.println(setPos);
    
}

void steeringToCenter() {
  analogWrite(STEERING_PIN_GREY, center[0]);
  analogWrite(STEERING_PIN_YELLOW, center[1]);
}

void steeringInit() {
	steeringToCenter();
	delay(1);//kad PWM dac turetu laiko nusistoveti
}

/**
 * angle - degress/10 i.e. 90 degrees = 900
 */

int16_t degreesToPosition(int16_t angle) {
	return (int16_t)128 + (((uint32_t)angle * STEPS_PER_DEGREE) / 1024);
}

void steeringSetAngle(int16_t angle) {
	lindeSteerTo(degreesToPosition(angle));
}

uint8_t steeringIsMoveDone() {
  return !isTurning;
}

void steeringRun() {
  if(isTurning && isTimeToTurnTheWheel()){
    if(Direction_CW == direction) {
      if(curPos + 1 <= setPos) {
        curPos++;
        analogWrite(STEERING_PIN_GREY, curPos + STEERING_PIN_GREY_OFFSET);
        analogWrite(STEERING_PIN_YELLOW, curPos + STEERING_PIN_YELLOW_OFFSET);
        // Serial.print(curPos + STEERING_PIN_GREY_OFFSET);
        // Serial.print(" ");
        // Serial.println(curPos + STEERING_PIN_YELLOW_OFFSET);
      } else {
        isTurning = 0;
      }
    } else {
      if(curPos - 1 >= setPos) {
        curPos--;
        analogWrite(STEERING_PIN_GREY, curPos + STEERING_PIN_GREY_OFFSET);
        analogWrite(STEERING_PIN_YELLOW, curPos + STEERING_PIN_YELLOW_OFFSET);
        // Serial.print(curPos + STEERING_PIN_GREY_OFFSET);
        // Serial.print(" ");
        // Serial.println(curPos + STEERING_PIN_YELLOW_OFFSET);
      } else {
        isTurning = 0;        
      }
    }
    lastTurnTs = millis();
  }
}

void steeringRunToPosition() {
	while(!steeringIsMoveDone()) {
		steeringRun();
	}
}
#endif

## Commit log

2017-03-06 line sensor design done, REV1 boards ordered
    [line-sensor.kicad_pcb, line-sensor.sch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]
2017-03-06 Some initial work on rs458 interface
    [line-interface.kicad_pcb, line-interface.sch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]
2017-03-06 Source transil
    [line-interface.sch]
2017-03-06 Add more leds
    [line-interface.sch]
2017-03-06 Finish sourcing the rest of components
    [line-interface.sch]
2017-03-06 Initial PCB component placement, start routing
    [line-interface.kicad_pcb]
2017-03-06 Add resistors to SPI lines, hook up to the connector
    [line-interface.sch]
2017-03-07 Finish routing the board, manufacturing order sent
    [User Library-SOD-123_DiodesInc.step, line-interface.kicad_pcb, line-interface.sch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]
2017-03-07 Add info about gas pedal hacking
    [isolated-controll.sch]
2017-03-08 Start laying out takeover/release part of the controller
    [pedal-takeover.sch, steering-wheel-takeover.sch, takeover.sch]
2017-03-08 Start putting the controller together, add various subsystems
    [controller.kicad_pcb, controller.sch, gaz-hack.sch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]
2017-03-09 Linde inerface
    initial commit
    [Linde-ctr-conn.sch, Linde.kicad_pcb]
2017-03-10 Steering added
    Steering wheel connector added
    [Linde-ctr-conn.sch]
2017-03-10 Throttle ctl schematics added
    [throttle_ctl.sch]
2017-03-13 Add more stuff to controller, start sourcing parts
    [break-h-bridge.sch, control-hacks.sch, controller.sch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]
2017-03-14 Change gas pedal interface so that it supports going up and down from the middle voltage so that it's compatible with Linde forklift gas mechanism
    [break-h-bridge.sch, control-hacks.sch, controller.sch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]
2017-03-14 More or less final controller board
    [break-h-bridge.sch, control-hacks.sch, controller.sch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]
2017-03-14 Some progress with controller board routing
    [break-h-bridge.sch, control-hacks.sch, controller.kicad_pcb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]
2017-03-17 firmware to appear
    Firmware for Arduino started to appear: Linde forklift steering code
    added
2017-03-17 Add firmware of the line sensor, basic stuff -- it spits out sensor data in '1' and '0' ascii strings. Also hardware fixez: * P-channel mosfet has different numbering * a new regulator for power hand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
    [line-interface.kicad_pcb, line-interface.sch]
2017-03-17 Add various footprints used in the project
2017-03-17 Arduino shield crap
2017-03-17 Finish the routing, add some significant fixes: *correct to-252 pin numbering * longer pads for relays * fix footprint of the optocouplers
    Also finish the routing
    [break-h-bridge.sch, control-hacks.sch, controller.kicad_pcb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]
2017-03-17 Move stuff around
    [line-sensor.kicad_pcb]
2017-03-18 Update the 5 and 2 pin terminal footprints, shuffle around some tracks
    [break-h-bridge.sch, controller.kicad_pcb, power.sch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]
2017-03-20 send controller and line interface boards for manufacturing
    [break-h-bridge.sch, control-hacks.sch, controller.kicad_pcb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]
2017-03-21 Linde steering
    Linde steering schematics and PCB added
    [Linde_steering.kicad_pcb, Linde_steering.sch, takeover.sch]
2017-03-21 Mounting holes added
    [Linde_steering.kicad_pcb, Linde_steering.sch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]
2017-03-23 ?CNC? plasma cut parts for electromechanics addons
    [Toyota drive wheel 1pcs 6mm ply normal.dxf, Toyota drive wheel 1pcs 6mm stepper holes.dxf, Toyota drive wheel 2pcs 6mm ply scaled.dxf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]
2017-03-24 Add filtering to sensor input
2017-03-24 Fix the line interface once more - input resistor has to be rated for 2W, also vias because no hole metallisation
    [line-interface.kicad_pcb, line-interface.sch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]
2017-03-24 Cleanup
    SMT GDS FET changed to more common GSD FET;
    OSHW and CC symbols added to copper layer;
    Gerbers updated and sent for manufacturing;
    Typeo fixed in Arduino code
    [Linde_steering.kicad_pcb, Linde_steering.sch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]
2017-03-26 HAL and controll logics started
    In function `sendControl':
    sketch/smalsiukas.cpp:81: undefined reference to
    `Smalsiukas::spiBitBang(unsigned char)'
    collect2.exe: error: ld returned 1 exit status
    exit status 1
    [smalsiukas.ino]
2017-04-04 The latest and the greatest test firmware.
    What works:
    * Emergency brake system
    * Steering wheel control, centering and backlash calibration (needs investigation as regadring to degree to step conversion)
    * Horn, lights, parking and key
    What's left:
    * Line sensor
    * Obstacle sensor
    [testFw.ino]
2017-04-04 Various fixes and comments to the controller board, also making it suitable for non-plated holes.
    [break-h-bridge.sch, control-hacks.sch, controller.kicad_pcb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]
2017-04-04 Add a state and some protocol flow control
2017-04-04 add comments with fixes I had to make
    [ctrl-switching.sch, gaz-hack.sch, power.sch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]
2017-04-06 A Linde forklift steering library that works
2017-04-06 Toyota truck DOES follow the line acceptably. Plus distance sensor and other enhantments
2017-04-07 It compiles and contains empty steering and gaz libraries
2017-04-07 Pin assignments revised
2017-04-07 Button works. Steering initial code
2017-04-07 Pin swap
2017-04-07 Steering DOES WORK
2017-04-07 Remove comments, fix steering pin assignments
    [pins.h]
2017-04-07 Steering test code, steering friendly startup code
2017-04-07 Release emergency brake when stopped by soft button
2017-04-10 Throttle controlled via add-on PWM board
2017-04-12 Add more expenses
    [expenses.csv]
2017-04-12 Last comments on the schematics
    [controller.sch, gaz-hack.sch]
2017-04-18 State LEDs added
    4 LEDs displays setup state. One the rightmost starts to blink, the
    forklift key may be turned on. Once the forklift is ready, press the
    START button and the movement begins.
    NB: ferrite cores must be added to the wiring (forklift side) to prevent
    EMI (when statics is discharging to the ground) going to the Linde
    controllers.
    [control.h, gaz_pwm.h, lindukas.ino]
2017-04-18 Fix the issue in the Toyota BT truck when line was not recognised or sensor disconnected
    [smalsiukas.ino]
2017-04-18 Add line detection fixes to lindukas
    [lindukas.ino]
